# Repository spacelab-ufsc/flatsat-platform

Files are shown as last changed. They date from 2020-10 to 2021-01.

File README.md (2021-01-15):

<h1 align="center">
	SpaceLab FlatSat Platform
	<br>
</h1>

<h4 align="center">FlatSat platform designed and developed by SpaceLab.</h4>

<p align="center">
	<a href="https://github.com/spacelab-ufsc/spacelab#versioning">
		
	</a>
	<a href="https://github.com/spacelab-ufsc/flatsat-platform/releases">
		
	</a>
	<a href="https://github.com/spacelab-ufsc/flatsat-platform/releases">
		
	</a>
	<a href="https://github.com/spacelab-ufsc/flatsat-platform/commits/master">
		
	</a>
	<a href="https://github.com/spacelab-ufsc/flatsat-platform/issues">
		
	</a>
	<a href="https://github.com/spacelab-ufsc/flatsat-platform/graphs/contributors">
		
	</a>
	<a href="#license">
		
	</a>
</p>

<p align="center">
  	<a href="#overview">Overview</a> •
  	<a href="#repository-organization">Repository Organizarion</a> •
  	<a href="#license">License</a> •
  	<a href="#releases">Releases</a> •
  	<a href="#notes">Notes</a>
</p>

<p align="center">
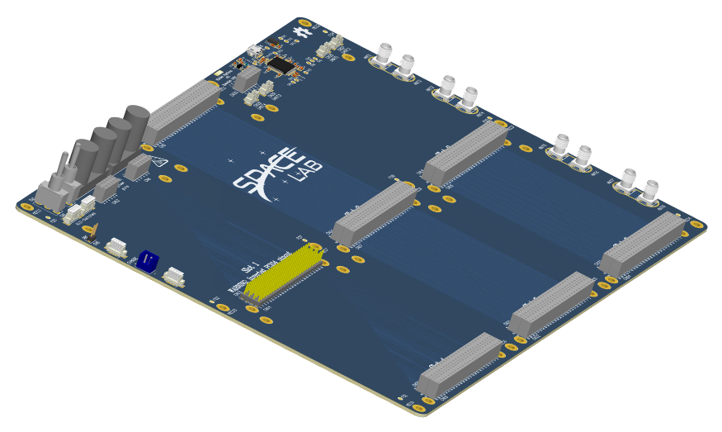
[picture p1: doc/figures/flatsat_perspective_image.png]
    
</p>

## Overview

The SpaceLab FlatSat Platform is a testbed for cubesat pcb modules. FlatSats enable easier, faster and secure method for testing subsystens indenpently or integrated in a flat design before going to assembly on a cubesat standard. The PCB can support up to 7 modules, all PC104 pins are interligated with each respective counterpart to flexibilize its use, only the particularity connection between modules need to be be taken into account.

## Repository Organization
	- doc: Technical FlatSat documentation.
	- hardware: Flatsat hardware project (sources and outputs).

## License

This project is licensed under CERN Open Hardware License (version 2) and Attribution-NoDerivatives 4.0 International (CC BY-ND 4.0).

## Releases

The FlatSat Platform hardware releases are synchronized in order to garantee compatibility. Then, using diferent versions might lead to unpredictable behavior. Refer to the [documentation](https://github.com/spacelab-ufsc/flatsat-platform/tree/master/doc) for compatibility notes.

## Notes

More info about the SpaceLab: [GitHub](https://github.com/spacelab-ufsc/spacelab) and [Website](https://spacelab.ufsc.br/en/home/).

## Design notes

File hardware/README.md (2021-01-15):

<h1 align="center">
	SpaceLab FlatSat Platform Hardware
	<br>
</h1>

<h4 align="center">FlatSat platform hardware project (sources, outputs, and documentation).</h4>

<p align="center">
    <a href="https://github.com/spacelab-ufsc/spacelab#versioning">
        
    </a>
    <a href="https://github.com/spacelab-ufsc/flatsat-platform/releases">
        
    </a>
    <a href="https://github.com/spacelab-ufsc/flatsat-platform/releases">
        
    </a>
    <a href="https://github.com/spacelab-ufsc/flatsat-platform/commits/master">
        
    </a>
    <a href="https://github.com/spacelab-ufsc/flatsat-platform/issues">
        
    </a>
    <a href="">
		
	</a>
    <a href="#license">
        
    </a>
    <a href="https://github.com/spacelab-ufsc/obdh">
        
    </a>
    <a href="https://github.com/spacelab-ufsc/flatsat-platform/tree/master/doc">
        
    </a>
</p>

<p align="center">
  	<a href="#hardware-overview">Hardware overview</a> •
  	<a href="#hardware-architecture-diagram">Architecture</a> •
  	<a href="#license">License</a> •
  	<a href="#notes">Notes</a>
</p>

<p align="center">
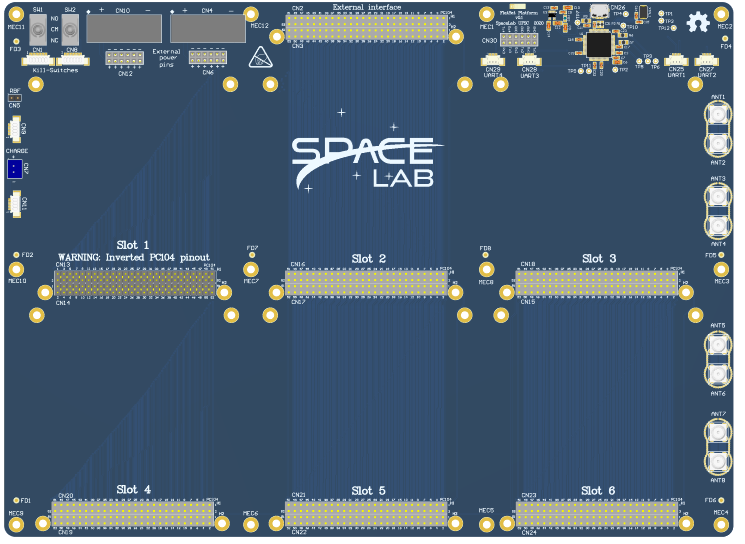
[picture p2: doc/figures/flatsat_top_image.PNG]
	
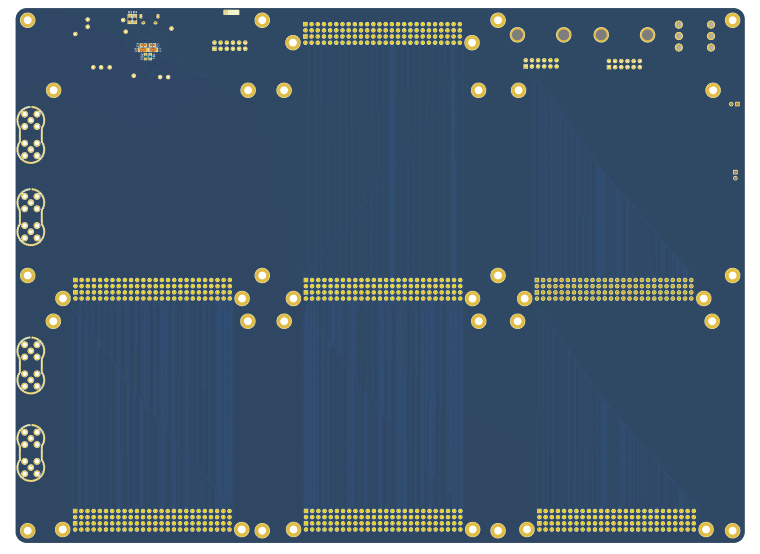
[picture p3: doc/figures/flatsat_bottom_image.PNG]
	
</p>

## Hardware overview

Currently in v0.1, the SpaceLab FlatSat Platform is a 300mmx220mm PCB composed by the following main hardware components:

* 7 PC104 connectors, one of them with inverted pinout.
* RBF pin header for a jumper and Kill-Switches with SPDTs.
* External charging for batteries thought JST and picoblade connectors.
* 2 separate binding posts (2 sets) for controled power supply and pin headers for external wiring. 
* 4 UART channels to micro USB B using FT4232H IC converter.
* 4 SMA connectors for antennas interfacing.

## Hardware architecture diagram

<p align="center">
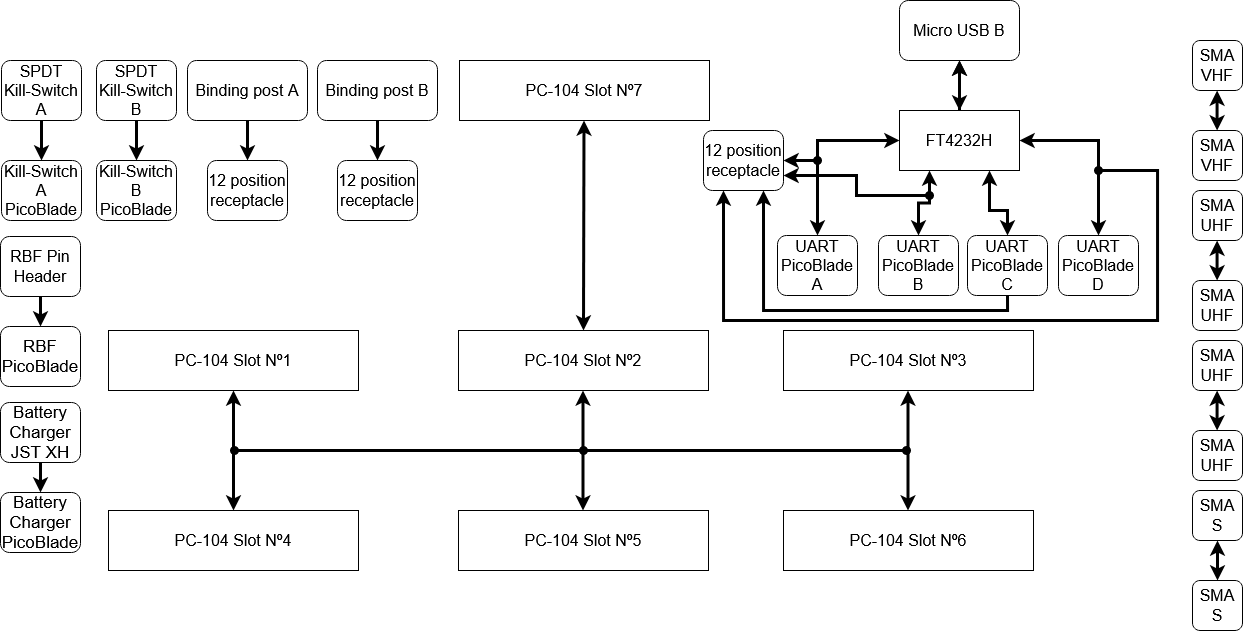
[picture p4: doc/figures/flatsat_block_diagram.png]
	
</p>

## License

The hardware part of this project is licensed under CERN Open Hardware License, version 2.

## Notes

More info about the SpaceLab: [GitHub](https://github.com/spacelab-ufsc/spacelab) and [Website](https://spacelab.ufsc.br/en/home/).

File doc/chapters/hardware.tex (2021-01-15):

%
% hardware.tex
%
% Copyright (C) 2021 by SpaceLab.
%
% Flatsat Platform Documentation
%
% This work is licensed under the Creative Commons Attribution-ShareAlike 4.0
% International License. To view a copy of this license,
% visit http://creativecommons.org/licenses/by-sa/4.0/.
%

%
% \brief Hardware chapter.
%
% \author Gabriel Mariano Marcelino <gabriel.marcelino@spacelab.ufsc.br>
% \author Yan Castro de Azeredo <yan.azeredo@spacelab.ufsc.br>
%
% \institution Universidade Federal de Santa Catarina (UFSC)
%
% \version 0.1.0
%
% \date 2020/10/11
%

\chapter{Hardware} \label{ch:hardware}

This chapter describes all the FlatSat's hardware interfaces in detail. On Figures \ref{fig:pcb-top} and \ref{fig:pcb-bottom} are displayed de top and bottom PCB prints.

\begin{figure}[!ht]
    \begin{center}
        
        \caption{FlatSat top PCB print.}
        \label{fig:pcb-top}
    \end{center}
\end{figure}

\begin{figure}[!ht]
    \begin{center}
        
        \caption{FlatSat bottom PCB print.}
        \label{fig:pcb-bottom}
    \end{center}
\end{figure}

\section{PC-104 Interfaces}

On SpaceLab's FlatSat Platform the PC-104 interfaces are composed by two 52 pins with 2.54 mm (0.1 inch) pitch connectors. Slots N$^{\circ}$2 to N$^{\circ}$7 has two \textit{SSW-126-01-G-D} and the slot N$^{\circ}$1 uses two \textit{TSW-126-07-G-D} connectors with inverted pinout, see Figures \ref{fig:n2-n7-slots} and \ref{fig:n1-slot}. All pins are interconected to flexiblesize the positioning of the modules on the platform. All slots have grounded unlabeled mounting holes for the modules, the labeled MEC1 to MEC12 holes are for the FlatStats stability feet.

\begin{figure}[!ht]
    \begin{center}
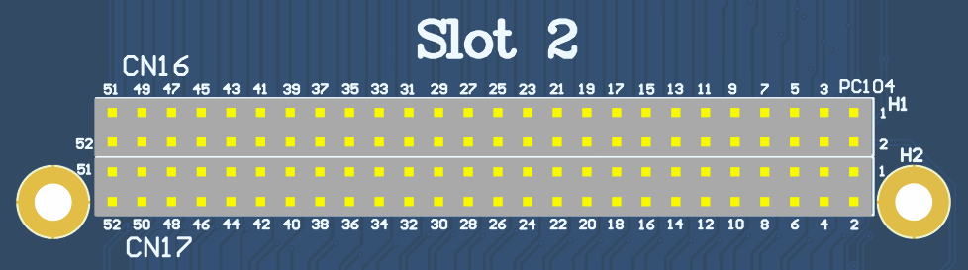
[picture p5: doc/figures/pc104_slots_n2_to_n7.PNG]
        
        \caption{FlatSat N$^{\circ}$2 PC-104 slot.}
        \label{fig:n2-n7-slots}
    \end{center}
\end{figure}

\begin{figure}[!ht]
    \begin{center}
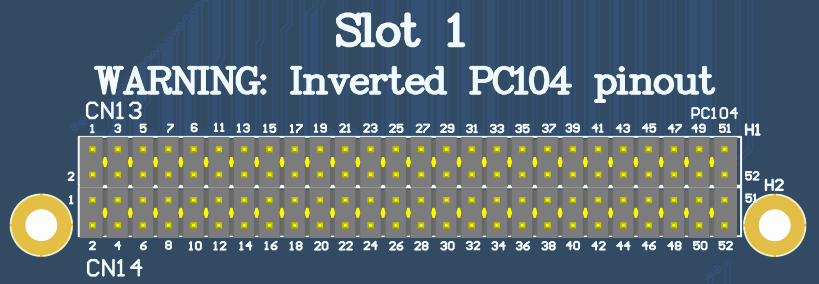
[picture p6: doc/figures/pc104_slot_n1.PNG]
        
        \caption{FlatSat N$^{\circ}$1 PC-104 slot.}
        \label{fig:n1-slot}
    \end{center}
\end{figure}

\section{Binding Posts and Power Receptacles}

Two sets of binding posts (\textit{4243-0}) can be mouted on the labeled CN4 and CN10 hole pads to be used for two external power supplies, see \autoref{fig:binding-posts}. The modules are powered via external jumper wires to the 12 position receptacle connectors (\textit{BCS-106-L-D-TE}) labeled CN6 and CN12. On the silkscreen the plus (+) signs are the positive power pins while the minus (-) signs are the GND pins.

\begin{figure}[!ht]
    \begin{center}
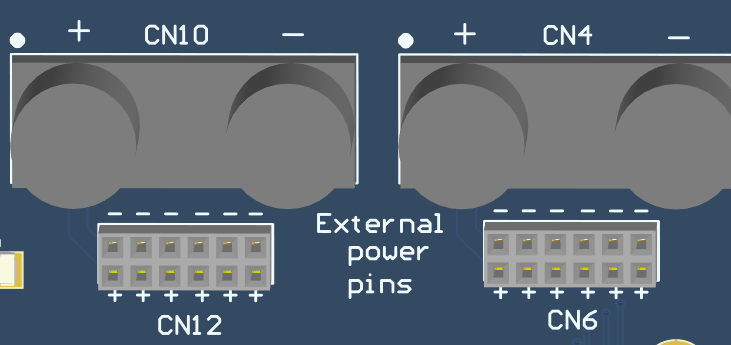
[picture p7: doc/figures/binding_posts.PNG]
        
        \caption{FlatSat binding posts and power receptables.}
        \label{fig:binding-posts}
    \end{center}
\end{figure}

\section{Charge Header}

On the board there is a JST XH 2 position header (\textit{B2B-XH-A-M(LF)(SN)}) for charging batteries, it can be seen in \autoref{fig:charge-connectors}. The component can suport up to 3000 mA of current, but it is advised to be used with less than 1500 mA. The 4 pin PicoBlade is to be connected to the EPS\nomenclature{\textbf{EPS}}{\textit{Electric Power System.}} module to make the interconnection for the JST header. The charge header also provides a detent lock for fastening and avoid a mistankenly reverse connection.

\begin{figure}[!ht]
    \begin{center}
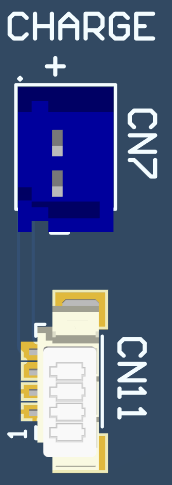
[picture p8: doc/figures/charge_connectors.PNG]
        
        \caption{FlatSat charge connectors.}
        \label{fig:charge-connectors}
    \end{center}
\end{figure}

\section{RBF Pin Header}

The platform has a RBF pin header that can seen \autoref{fig:rbf-connectors}. The interconnection between the header and the EPS module is done by a 4 pin PicoBlade.

\begin{figure}[!ht]
    \begin{center}
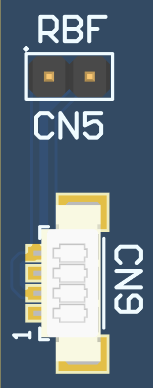
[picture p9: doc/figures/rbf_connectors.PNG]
        
        \caption{FlatSat RBF connectors.}
        \label{fig:rbf-connectors}
    \end{center}
\end{figure}

\section {SPDT Kill-Switches}

The kill-switches uses SPDT switches (\textit{100SP1T1B4M2QE}) for powering off the EPS module, see \autoref{fig:kill-switches-connectors}. The power off states are seen on \autoref{fig:kill-switches-states}, they are also present on the hardware schematics. The SPDTs are interconnected to the EPS module via two 6 pin PicoBlade connectors labeled CN1 and CN8.

\begin{figure}[!ht]
    \begin{center}
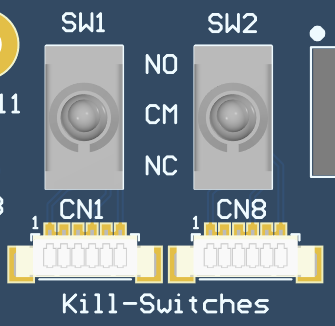
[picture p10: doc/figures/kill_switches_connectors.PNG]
        
        \caption{FlatSat kill-switches connectors.}
        \label{fig:kill-switches-connectors}
    \end{center}
\end{figure}

\begin{figure}[!ht]
    \begin{center}
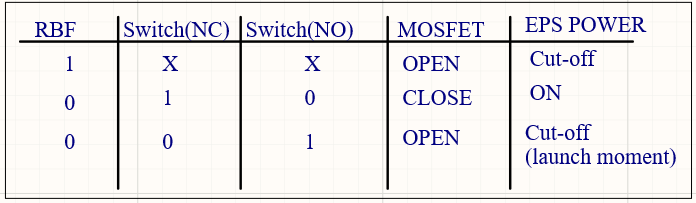
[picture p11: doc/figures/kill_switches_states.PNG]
        
        \caption{FlatSat kill-switches states.}
        \label{fig:kill-switches-states}
    \end{center}
\end{figure}

\section{Antenna Interfaces}

\subsection{SMA connectors}

On the PCB there are SMA connectors (\textit{132134-15}) labeled ANT1 to ANT8 for connecting VHF\nomenclature{\textbf{VHF}}{\textit{Very High Frequency.}}, UHF\nomenclature{\textbf{UHF}}{\textit{Ultra High Frequency.}} and S-Band antennas, see \autoref{fig:antennas-smas}. The receiver (RX) antenna is to be connected to one of the SMA, while the transmitter (TX) goes to the other connector and to the CubeSat module. The impedance control (see \autoref{fig:rf-track-width-calc}) and power dissipation (see \autoref{fig:rf-track-width-power-calc}) where approximately calculated for all 3 bands. As the FlatSat platform is to be used in light testing the aproximations where considered acceptable for the project.

\begin{figure}[!ht]
    \begin{center}
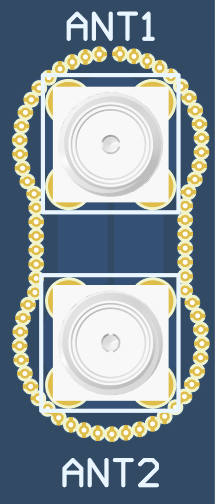
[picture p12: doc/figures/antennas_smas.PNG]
        
        \caption{FlatSat SMA connectors.}
        \label{fig:antennas-smas}
    \end{center}
\end{figure}

\subsection{Impedance Control of the RF Tracks}

\begin{figure}[!ht]
    \begin{center}
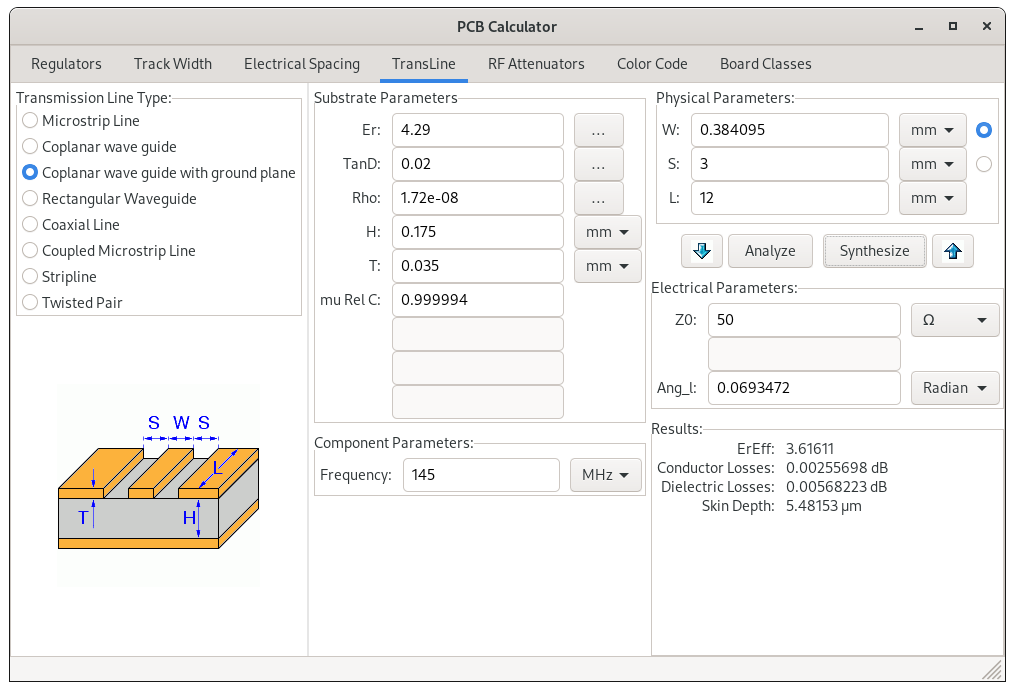
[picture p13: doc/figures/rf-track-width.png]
        
        \caption{Calculation of the width of the RF tracks.}
        \label{fig:rf-track-width-calc}
    \end{center}
\end{figure}

\begin{figure}[!ht]
    \begin{center}
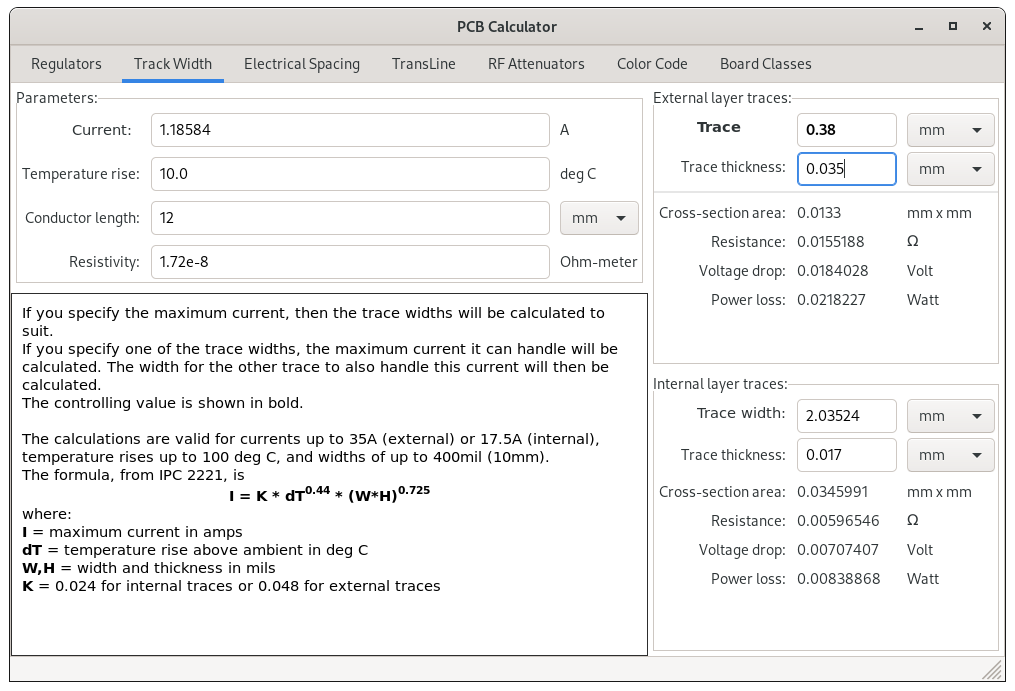
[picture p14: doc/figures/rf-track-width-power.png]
        
        \caption{Power dissipation of the RF tracks.}
        \label{fig:rf-track-width-power-calc}
    \end{center}
\end{figure}

\section{UART to USB Converter}

There is a UART to USB converter circuit built-in the FlatSat platform for debbuging pourposes for four independent modules, it can be seen on \autoref{fig:ft4232h-circuit}. The subcircuit is self powered from a USB cable connecting a computer to a micro USB type B port (\textit{10118194-0001LF}). The USB Bridge converter IC\nomenclature{\textbf{IC}}{\textit{Integrated Circuit.}} is the \textit{FT4232HL-REEL} from FTDI. PicoBlade connectors are used for connecting the IC to the modules, see Figures \ref{fig:uart-picoblades-1} and \ref{fig:uart-picoblades-2}. It is also possible to use jumper wires connecting the 12 Position receptacle connector (\textit{BCS-106-L-D-TE}) labeled CN30 to the modules if PicoBlades are not used.

\begin{figure}[!ht]
    \begin{center}
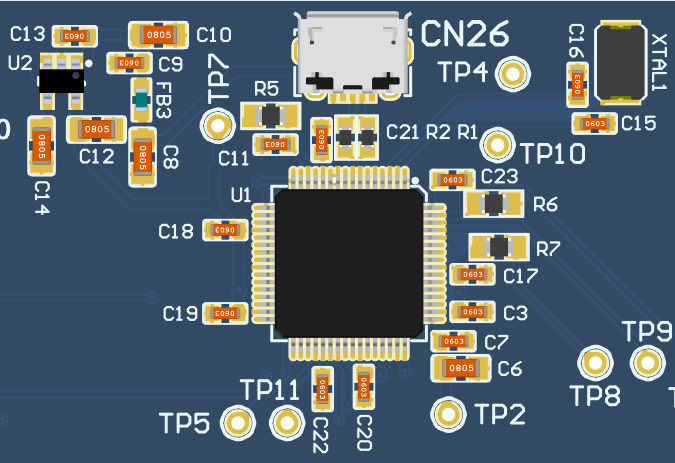
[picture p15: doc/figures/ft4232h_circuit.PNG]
        
        \caption{Top view of the UART to USB converter circuit.}
        \label{fig:ft4232h-circuit}
    \end{center}
\end{figure}

\begin{figure}[!ht]
    \begin{center}
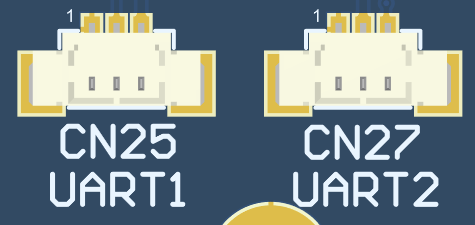
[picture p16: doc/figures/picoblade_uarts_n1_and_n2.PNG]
        
        \caption{UART PicoBlade N$^{\circ}$1 and N$^{\circ}$2 connectors.}
        \label{fig:uart-picoblades-1}
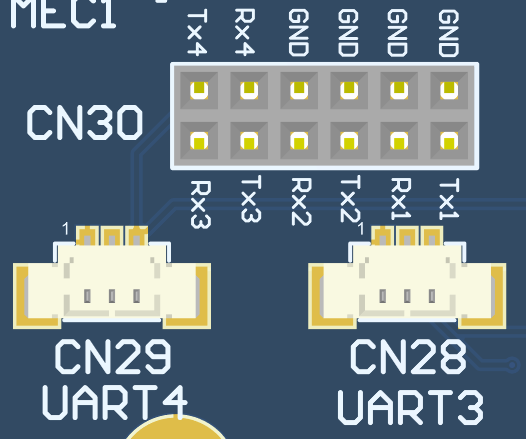
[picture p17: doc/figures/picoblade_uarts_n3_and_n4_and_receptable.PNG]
        
        \caption{UART PicoBlade N$^{\circ}$3 and N$^{\circ}$4 connectors and receptable.}
        \label{fig:uart-picoblades-2}
    \end{center}
\end{figure}

\section{Test Points}

The FlatSat has test points for the UART to USB converter circuit. The \autoref{tab:testpoints} displays their labels and description.

\begin{table}[!h]
    \centering
    \begin{tabular}{cllll}
        \toprule[1.5pt]
        \textit{Label} & \textit{Description} \\
        \midrule
        TP1                & (VPLL) 3V3 FT4232H power input. \\
        TP2                & (VREGOUT) 1V8 FT4232H internal power output. \\
        TP3                & (VPHY) 3V3 FT4232H power input. \\
        TP4                & (REF) Current reference for FT4232H. \\
        TP5                & (RESET\#) Reset input for FT4232H. \\
        TP6                & (EECS) EEPROM chip select - pulled down by 10k resistor. \\
        TP7                & (VCCIO) I/O interface 3V3 power supply input. \\
        TP8                & (EEDATA) EEPROM data I/O - pulled up by 10k resistor. \\
        TP9                & (EECLK) Clock signal to EEPROM - not used. \\
        TP10               & (PWREN\#) Active low power-enable output. \\
        TP11               & (SUSPEND\#) Active low when USB is in suspend mode. \\
        TP12               & (GND) 0V ground input for FT4232H.\\
        \bottomrule[1.5pt]
    \end{tabular}
    \caption{FlatSat test points.}
    \label{tab:testpoints}
\end{table}

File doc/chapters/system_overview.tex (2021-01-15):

%
% system_overview.tex
%
% Copyright (C) 2021 by SpaceLab.
%
% Flatsat Platform Documentation
%
% This work is licensed under the Creative Commons Attribution-ShareAlike 4.0
% International License. To view a copy of this license,
% visit http://creativecommons.org/licenses/by-sa/4.0/.
%

%
% \brief System Overview chapter.
%
% \author Gabriel Mariano Marcelino <gabriel.marcelino@spacelab.ufsc.br>
% \author Yan Castro de Azeredo <yan.azeredo@spacelab.ufsc.br>
%
% \institution Universidade Federal de Santa Catarina (UFSC)
%
% \version 0.1.0
%
% \date 2020/12/17
%

\chapter{System Overview} \label{ch:system-overview}

The FlatSat form factor choosen for this project is a retangular one piece design. On its current version v0.1 the platform can be purelly used hardware wise. The hardware block diagram can be seen on \autoref{fig:block-diagram}. The PC-104 slot N$^{\circ}$7 is supossed to be used for a extra interface, shield or another FlatSat platform.

\section{Block Diagram}

\begin{figure}[!ht]
    \begin{center}
        
        \caption{FlatSat hardware block diagram.}
        \label{fig:block-diagram}
    \end{center}
\end{figure}

\section{Board Dimensions}

The board is a retangular PCB with linear dimensions of 300$\times$220 mm. The full mechanical specs of the platform can be seen on its draftsman document available at it's GitHub repository \cite{flatsat-draftsman}.

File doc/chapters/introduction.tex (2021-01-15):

%
% introduction.tex
%
% Copyright (C) 2020 by SpaceLab.
%
% Flatsat Platform Documentation
%
% This work is licensed under the Creative Commons Attribution-ShareAlike 4.0
% International License. To view a copy of this license,
% visit http://creativecommons.org/licenses/by-sa/4.0/.
%

%
% \brief Introduction chapter.
%
% \authors: Gabriel Mariano Marcelino <gabriel.marcelino@spacelab.ufsc.br> and Yan Castro de Azeredo <yan.azeredo@spacelab.ufsc.br>
%
% \institution Universidade Federal de Santa Catarina (UFSC)
%
% \version 0.1.0
%
% \date 2020/07/16
%

\chapter{Introduction} \label{ch:introduction}

The SpaceLab FlatSat Platform is a testbed for CubeSat PCB\nomenclature{\textbf{PCB}}{\textit{Printed Circuit Board.}} modules. FlatSats enable easier, faster and a secure method for testing subsystens independently while been integrated in a flat design before going to integration on a CubeSat form factor. The PCB can support up to 7 modules, all PC-104 pins are interligated to flexibilize its use, only the particularity connection between modules need to be be taken into account. One PC-104 has inverted pinout, the board also makes it possible to have two seperate power supplies, a UART\nomenclature{\textbf{UART}}{\textit{Universal Asynchronous Receiver/Transmitter.}} to USB\nomenclature{\textbf{USB}}{\textit{Universal Serial Bus.}} converter for 4 modules, kill-switches activation though SPDTs\nomenclature{\textbf{SPDT}}{\textit{Single Pole, Double Throw.}}, Remove Before Flight (RBF\nomenclature{\textbf{RBF}}{\textit{Remove Before Flight.}}) pin header, connector for charging batteries and SMA\nomenclature{\textbf{SMA}}{\textit{SubMiniature version A.}} connectors for antennas. This project is to be used on the GOLDS-UFSC mission \cite{golds-ufsc} during test phase.

\begin{figure}[!ht]
    \begin{center}
        
        \caption{3D view of the FlatSat PCB.}
        \label{fig:pcb-3d}
    \end{center}
\end{figure}

All the project, source and documentation files are available freely on a GitHub repository \cite{flatsat-platform-repo} under its respective licenses.

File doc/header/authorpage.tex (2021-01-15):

%
% authorpage.tex
%
% Copyright (C) 2021 SpaceLab.
%
% Flatsat Platform Documentation
%
% This work is licensed under the Creative Commons Attribution-ShareAlike 4.0
% International License. To view a copy of this license,
% visit http://creativecommons.org/licenses/by-sa/4.0/.
%

%
% \brief Author page.
%
% \author Gabriel Mariano Marcelino <gabriel.marcelino@spacelab.ufsc.br>
%
% \institution Universidade Federal de Santa Catarina (UFSC)
%
% \version 0.1.0
%
% \date 2020/07/16
%

\thispagestyle{empty}

\begin{center}

\textbf{\thetitle}

\textit{January, 2021}

\vspace{1cm}

\textbf{Project Chief:}

Eduardo Augusto Bezerra

\vspace{1cm}

\textbf{Authors:}

Yan Castro de Azeredo \\

\vspace{1cm}

\textbf{Contributing Authors:}

Gabriel Mariano Marcelino \\
André Martins Pio de Mattos \\

\vspace{1cm}

\textbf{Revision Control:}

\end{center}

\begin{table}[!ht]
    \begin{center}
        \begin{tabular}{cL{5cm}L{5.5cm}C{2cm}}
            \toprule[1.5pt]
            \textbf{Version} & \textbf{Author}  & \textbf{Changes}    & \textbf{Date} \\
            \midrule
            0.0     & G. M. Marcelino           & Document creation   & 2020/10/11 \\
            0.1     & Y. C. de Azeredo          & First release       & 2021/01/04 \\
                    &                           &                     &            \\
                    &                           &                     &            \\
            \bottomrule[1.5pt]
        \end{tabular}
    \end{center}
\end{table}

\vfill

\begin{figure}[!h]
	\begin{center}
		
	\end{center}
\end{figure}

\textcopyright\  2021 by SpaceLab. \thetitle. This work is licensed under the Creative Commons Attribution-ShareAlike 4.0 International License. To view a copy of this license, visit \href{http://creativecommons.org/licenses/by-sa/4.0/}{http://creativecommons.org/licenses/by-sa/4.0/}.

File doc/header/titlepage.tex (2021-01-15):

%
% titlepage.tex
%
% Copyright (C) 2021 by SpaceLab.
%
% Flatsat Platform Documentation
%
% This work is licensed under the Creative Commons Attribution-ShareAlike 4.0
% International License. To view a copy of this license,
% visit http://creativecommons.org/licenses/by-sa/4.0/.
%

%
% \brief Title page.
%
% \author Gabriel Mariano Marcelino <gabriel.marcelino@spacelab.ufsc.br>
%
% \institution Universidade Federal de Santa Catarina (UFSC)
%
% \version 0.1.0
%
% \date 2020/07/16
%

\begin{titlepage}

\thispagestyle{empty}

\begin{flushleft}
SLB-FLATSAT-DOC-v0.1
\end{flushleft}

\vspace{1cm}

\begin{figure}[!ht]
    \begin{flushleft}
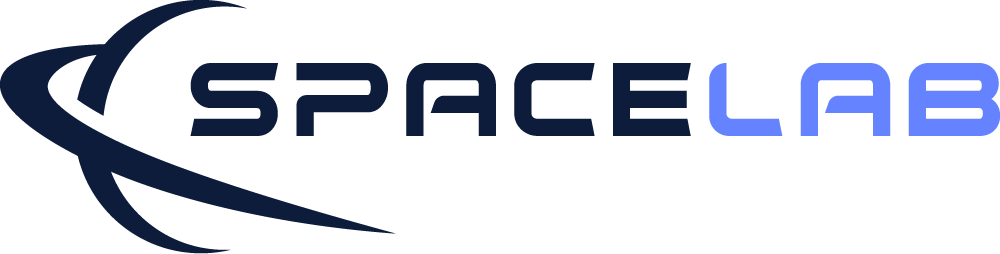
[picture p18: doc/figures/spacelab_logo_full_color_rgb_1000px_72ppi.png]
        
    \end{flushleft}
\end{figure}

\begin{flushleft}
\Huge{\textbf{\thetitle}}
\rule[0pt]{\textwidth}{5pt}
\end{flushleft}

\vspace{0.2cm}

\begin{flushleft}
\textit{\thetitle} \\
\textit{SpaceLab, Universidade Federal de Santa Catarina, Florianópolis - Brazil}
\end{flushleft}

\vfill
\vfill

\begin{flushright}
January 2021
\end{flushright}

\end{titlepage}

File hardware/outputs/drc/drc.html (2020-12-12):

Altium

# Design Rule Verification Report

Date: | | 11/5/2020
Time: | | 8:09:18 PM
Elapsed Time: | | 00:00:04
Filename: | | C:\Users\Yan Azeredo\Desktop\SpaceLab\flatsat-platform\hardware\sources\board_layout.PcbDoc

Warnings: | | 0
Rule Violations: | | 0

## Summary

Warnings | Count
Total | 0

Rule Violations | Count
Clearance Constraint (Gap=0.178mm) (InNetClass('S')),(InNetClass('S')) | 0
Clearance Constraint (Gap=0.178mm) (All),(All) | 0
Short-Circuit Constraint (Allowed=No) (All),(All) | 0
Un-Routed Net Constraint ( (All) ) | 0
Modified Polygon (Allow modified: No), (Allow shelved: No) | 0
Width Constraint (Min=0.127mm) (Max=1.778mm) (Preferred=0.381mm) (All) | 0
Power Plane Connect Rule(Direct Connect )(Expansion=0.508mm) (Conductor Width=0.254mm) (Air Gap=0.254mm) (Entries=4) (Not All) | 0
Power Plane Connect Rule(Relief Connect )(Expansion=0.508mm) (Conductor Width=0.254mm) (Air Gap=0.254mm) (Entries=4) (All) | 0
Power Plane Connect Rule(Direct Connect )(Expansion=0.508mm) (Conductor Width=0.254mm) (Air Gap=0.254mm) (Entries=4) (InNetClass('power')) | 0
Hole Size Constraint (Min=0.025mm) (Max=5.08mm) (All) | 0
Hole To Hole Clearance (Gap=0.254mm) (All),(All) | 0
Minimum Solder Mask Sliver (Gap=0mm) (All),(All) | 0
Silk To Solder Mask (Clearance=0mm) (IsPad),(All) | 0
Silk to Silk (Clearance=0.127mm) (All),(All) | 0
Net Antennae (Tolerance=0mm) (All) | 0
Height Constraint (Min=0mm) (Max=1790.783mm) (Prefered=12.7mm) ('PCB_Project_Batteries') | 0
Total | 0

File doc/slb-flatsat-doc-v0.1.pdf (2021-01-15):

SLB-FLATSAT-DOC-v0.1

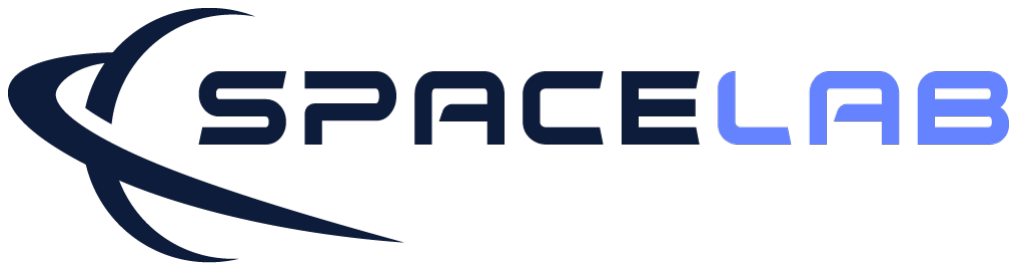
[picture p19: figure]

# Flatsat Platform Documentation

Flatsat Platform Documentation
SpaceLab, Universidade Federal de Santa Catarina, Florianópolis - Brazil

January 2021

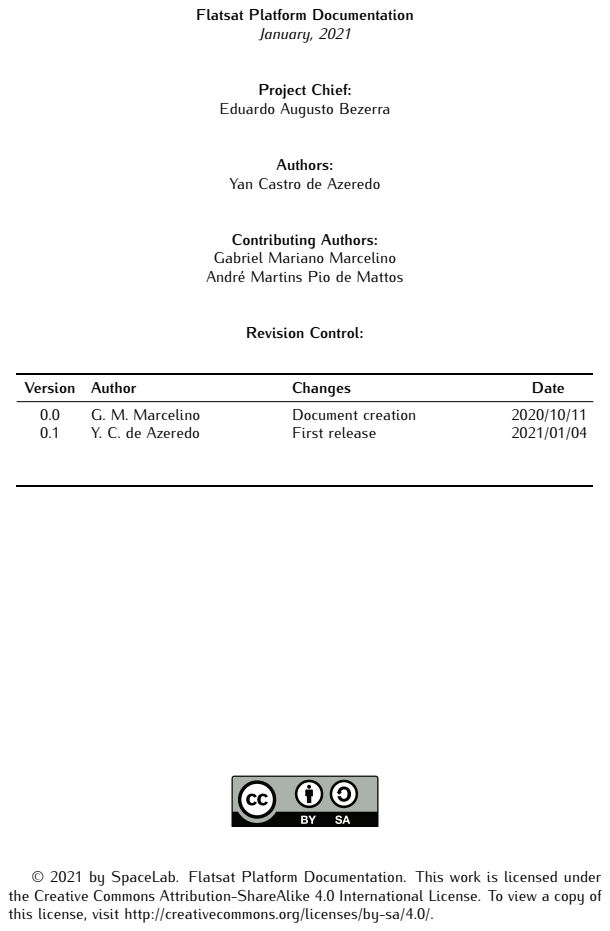
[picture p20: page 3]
January, 2021; Authors:; Revision Control:; Version Author; Changes; Date; G. M. Marcelino; Document creation; Y. C. de Azeredo; First release

Flatsat Platform Documentation

Project Chief:
Eduardo Augusto Bezerra

Yan Castro de Azeredo

Contributing Authors:
Gabriel Mariano Marcelino
André Martins Pio de Mattos

© 2021 by SpaceLab. Flatsat Platform Documentation. This work is licensed under
the Creative Commons Attribution-ShareAlike 4.0 International License. To view a copy of
this license, visit http://creativecommons.org/licenses/by-sa/4.0/.

## List of Figures

1.1 3D view of the FlatSat PCB | | 1
2.1 FlatSat hardware block diagram | | 3
3.1 FlatSat top PCB print | | 5
3.2 FlatSat bottom PCB print | | 6
3.3 FlatSat N◦2 PC-104 slot | | 6
3.4 FlatSat N◦1 PC-104 slot | | 6
3.5 FlatSat binding posts and power receptables | | 7
3.6 FlatSat charge connectors | | 7
3.7 FlatSat RBF connectors | | 8
3.8 FlatSat kill-switches connectors | | 8
3.9 FlatSat kill-switches states | | 9
3.10 FlatSat SMA connectors | | 9
3.11 Calculation of the width of the RF tracks | | 10
3.12 Power dissipation of the RF tracks | | 11
3.13 Top view of the UART to USB converter circuit | | 11
3.14 UART PicoBlade N◦1 and N◦2 connectors | | 12
3.15 UART PicoBlade N◦3 and N◦4 connectors and receptable | | 12
4.1 Bottom view of the UART to USB converter circuit | | 14
4.2 EPS mounted on N◦1 slot on a EDA tool | | 14
4.3 OBDH mounted on N◦2 slot on a EDA tool | | 14

v

## List of Tables

3.1 FlatSat test points | 12

vii

## Nomenclature

AWG | American Wire Gauge.
BOM | Bill Of Materials.
DC | Direct Current.
DNP | Do Not Place.

EEPROM Electrically-Erasable Programmable Read-Only Memory.

EMC | Electromagnetic Compatibility.
EPS | Electric Power System.
IC | Integrated Circuit.
OBDH | On-Board Data Handling.
PCB | Printed Circuit Board.
PC | Personal Computer.
RBF | Remove Before Flight.
SMA | SubMiniature version A.
SPDT | Single Pole, Double Throw.
UART | Universal Asynchronous Receiver/Transmitter.
UHF | Ultra High Frequency.
USB | Universal Serial Bus.
VHF | Very High Frequency.

ix

## Contents

List of Figures | v
List of Tables | vii
Nomenclature | ix
1 Introduction | 1
2 System Overview | 3
3 Hardware | 5
4 Board Assembly | 13
5 Usage Instructions | 15
References | 17

xi

## CHAPTER 1

## Introduction

The SpaceLab FlatSat Platform is a testbed for CubeSat PCB modules. FlatSats enable easier, faster and a secure method for testing subsystens independently while been integrated in a flat design before going to integration on a CubeSat form factor. The PCB can support up to 7 modules, all PC-104 pins are interligated to flexibilize its use, only the particularity connection between modules need to be be taken into account. One PC-104 has inverted pinout, the board also makes it possible to have two seperate power supplies, a UART to USB converter for 4 modules, kill-switches activation though SPDTs, Remove Before Flight (RBF) pin header, connector for charging batteries and SMA connectors for antennas. This project is to be used on the GOLDS-UFSC mission
[1] during test phase.

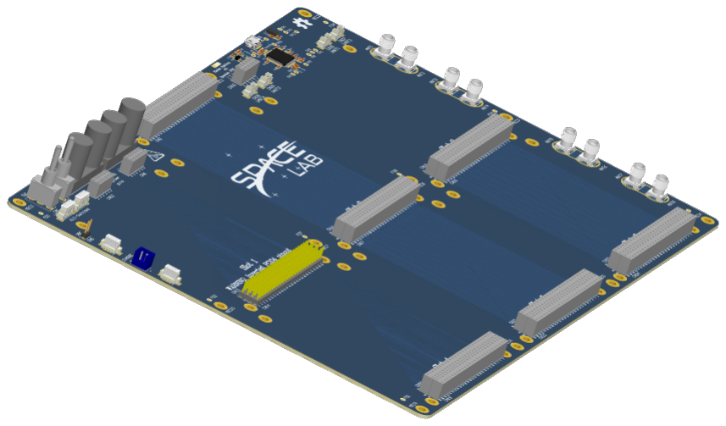
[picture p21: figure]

Figure 1.1: 3D view of the FlatSat PCB.

All the project, source and documentation files are available freely on a GitHub repository [2] under its respective licenses.

## CHAPTER 2

## System Overview

The FlatSat form factor choosen for this project is a retangular one piece design. On its current version v0.1 the platform can be purelly used hardware wise. The hardware block diagram can be seen on Figure 2.1. The PC-104 slot N◦7 is supossed to be used for a extra interface, shield or another FlatSat platform.

## 2.1 Block Diagram

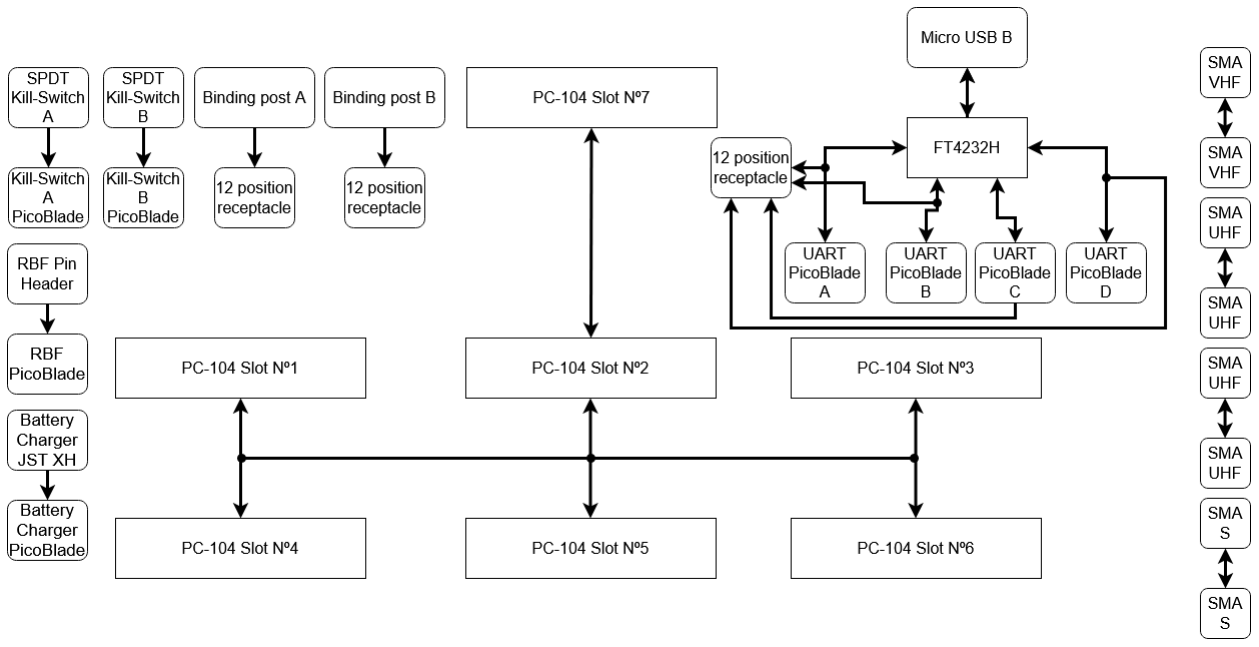
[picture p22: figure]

Figure 2.1: FlatSat hardware block diagram.

## 2.2 Board Dimensions

The board is a retangular PCB with linear dimensions of 300×220 mm. The full mechanical specs of the platform can be seen on its draftsman document available at it’s GitHub repository [3].

## CHAPTER 3

## Hardware

This chapter describes all the FlatSat’s hardware interfaces in detail. On Figures 3.1 and 3.2 are displayed de top and bottom PCB prints.

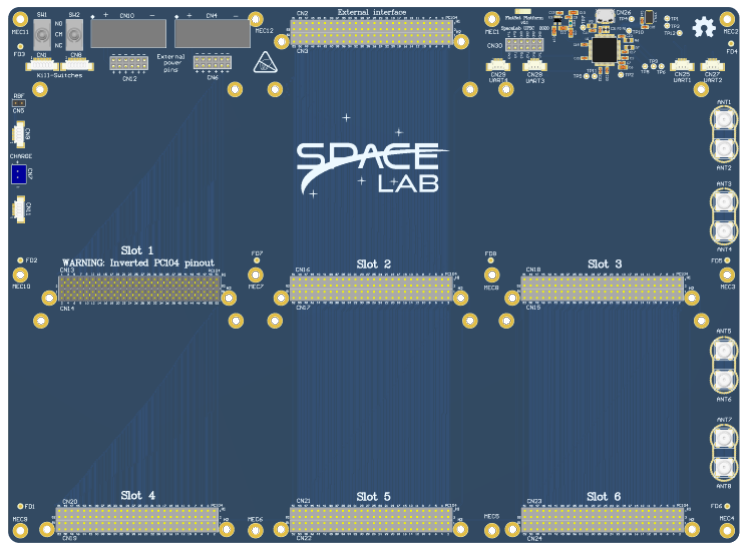
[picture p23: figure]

Figure 3.1: FlatSat top PCB print.

## 3.1 PC-104 Interfaces

On SpaceLab’s FlatSat Platform the PC-104 interfaces are composed by two 52 pins with 2.54 mm (0.1 inch) pitch connectors. Slots N◦2 to N◦7 has two SSW-126-01-G-D and the slot N◦1 uses two TSW-126-07-G-D connectors with inverted pinout, see Figures 3.3 and 3.4. All pins are interconected to flexiblesize the positioning of the modules on the platform. All slots have grounded unlabeled mounting holes for the modules, the labeled MEC1 to MEC12 holes are for the FlatStats stability feet.

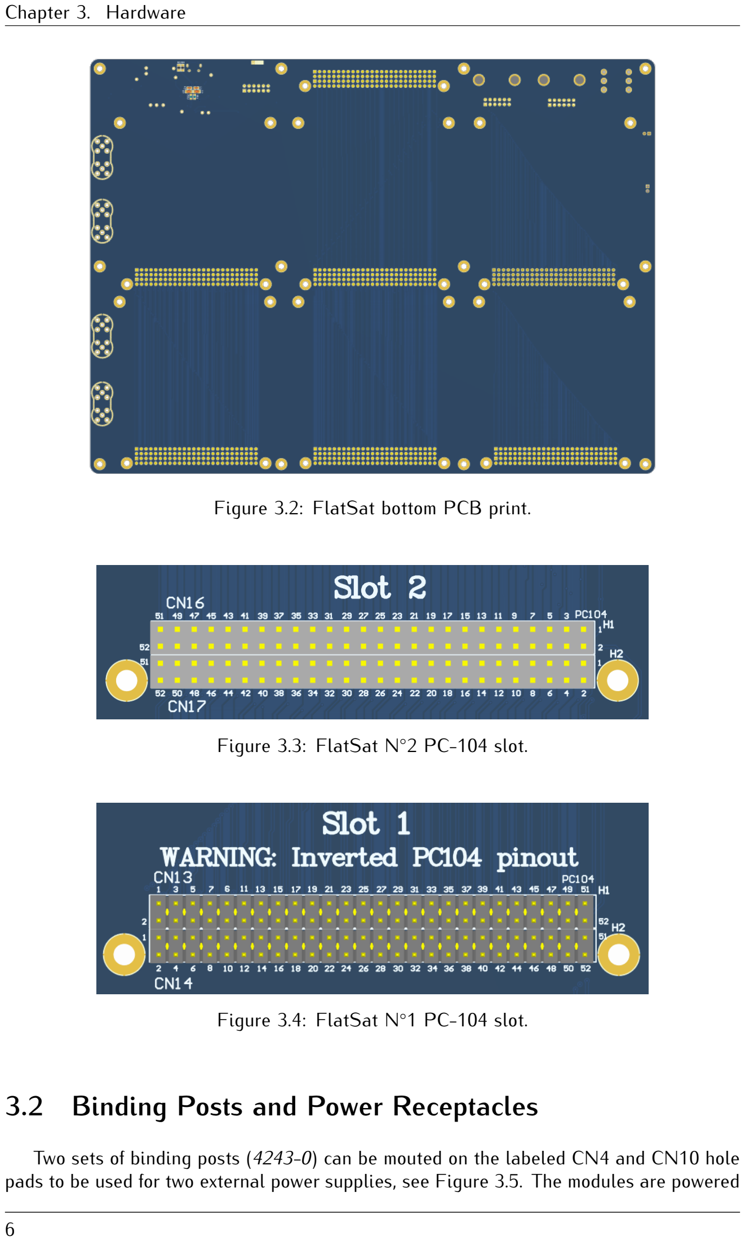
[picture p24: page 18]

Chapter 3. Hardware

Figure 3.2: FlatSat bottom PCB print.

Figure 3.3: FlatSat N◦2 PC-104 slot.

Figure 3.4: FlatSat N◦1 PC-104 slot.

## 3.2 Binding Posts and Power Receptacles

Two sets of binding posts (4243-0) can be mouted on the labeled CN4 and CN10 hole pads to be used for two external power supplies, see Figure 3.5. The modules are powered

3.3. Charge Header

via external jumper wires to the 12 position receptacle connectors (BCS-106-L-D-TE) labeled CN6 and CN12. On the silkscreen the plus (+) signs are the positive power pins while the minus (-) signs are the GND pins.


Figure 3.5: FlatSat binding posts and power receptables.

## 3.3 Charge Header

On the board there is a JST XH 2 position header (B2B-XH-A-M(LF)(SN)) for charging batteries, it can be seen in Figure 3.6. The component can suport up to 3000 mA of current, but it is advised to be used with less than 1500 mA. The 4 pin PicoBlade is to be connected to the EPS module to make the interconnection for the JST header. The charge header also provides a detent lock for fastening and avoid a mistankenly reverse connection.

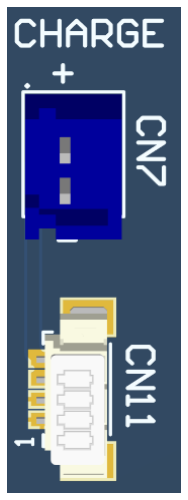
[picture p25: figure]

Figure 3.6: FlatSat charge connectors.

Chapter 3. Hardware

## 3.4 RBF Pin Header

The platform has a RBF pin header that can seen Figure 3.7. The interconnection between the header and the EPS module is done by a 4 pin PicoBlade.


Figure 3.7: FlatSat RBF connectors.

## 3.5 SPDT Kill-Switches

The kill-switches uses SPDT switches (100SP1T1B4M2QE) for powering off the EPS module, see Figure 3.8. The power off states are seen on Figure 3.9, they are also present on the hardware schematics. The SPDTs are interconnected to the EPS module via two 6 pin PicoBlade connectors labeled CN1 and CN8.


Figure 3.8: FlatSat kill-switches connectors.

3.6. Antenna Interfaces


Figure 3.9: FlatSat kill-switches states.

## 3.6 Antenna Interfaces

### 3.6.1 SMA connectors

On the PCB there are SMA connectors (132134-15) labeled ANT1 to ANT8 for connecting VHF, UHF and S-Band antennas, see Figure 3.10. The receiver (RX) antenna is to be connected to one of the SMA, while the transmitter (TX) goes to the other connector and to the CubeSat module. The impedance control (see Figure 3.11) and power dissipation (see Figure 3.12) where approximately calculated for all 3 bands. As the FlatSat platform is to be used in light testing the aproximations where considered acceptable for the project.


Figure 3.10: FlatSat SMA connectors.

### 3.6.2 Impedance Control of the RF Tracks

## 3.7 UART to USB Converter

There is a UART to USB converter circuit built-in the FlatSat platform for debbuging pourposes for four independent modules, it can be seen on Figure 3.13. The subcircuit is self powered from a USB cable connecting a computer to a micro USB type B port (10118194-0001LF). The USB Bridge converter IC is the FT4232HL-REEL from FTDI. PicoBlade connectors are used for connecting the IC to the modules, see Figures 3.14

Chapter 3. Hardware


Figure 3.11: Calculation of the width of the RF tracks.

and 3.15. It is also possible to use jumper wires connecting the 12 Position receptacle connector (BCS-106-L-D-TE) labeled CN30 to the modules if PicoBlades are not used.

## 3.8 Test Points

The FlatSat has test points for the UART to USB converter circuit. The Table 3.1 displays their labels and description.


3.8. Test Points

Figure 3.12: Power dissipation of the RF tracks.

Figure 3.13: Top view of the UART to USB converter circuit.

Chapter 3. Hardware


Figure 3.14: UART PicoBlade N◦1 and N◦2 connectors.


Figure 3.15: UART PicoBlade N◦3 and N◦4 connectors and receptable.

Label Description

TP1 | (VPLL) 3V3 FT4232H power input.
TP2 | (VREGOUT) 1V8 FT4232H internal power output.
TP3 | (VPHY) 3V3 FT4232H power input.
TP4 | (REF) Current reference for FT4232H.
TP5 | (RESET#) Reset input for FT4232H.
TP6 | (EECS) EEPROM chip select - pulled down by 10k resistor.
TP7 | (VCCIO) I/O interface 3V3 power supply input.
TP8 | (EEDATA) EEPROM data I/O - pulled up by 10k resistor.
TP9 | (EECLK) Clock signal to EEPROM - not used.
TP10 (PWREN#) Active low power-enable output.
TP11 (SUSPEND#) Active low when USB is in suspend mode. TP12 (GND) 0V ground input for FT4232H.

Table 3.1: FlatSat test points.

## CHAPTER 4

## Board Assembly

The hardware project has the Bill of Material (BOM) avalaible at its GitHub repository in excel spreeadsheets format. The PCB can be assembled by a Pick-and-place machine using the .txt file found on the hardware/fabrication folder if desired, fiducials labeled FD# are placed to make this possible.

## 4.1 FlatSat Stabillity Feet

On the PCB there are labeled MEC1 to MEC12 mouting holes on the edges and in the middle of the board to be used for stabillity feet when the board is placed on top of a test bench.

## 4.2 DNP Components

There is only one Do Not Place (DNP) component present in the USB to UART circuit, it is the labeled R4 pad with 0805 size (2012 metric) available for soldering the micro USB type B chassi to GND for Electromagnetic compatibility (EMC) see Figure 4.1. This can be done soldering a zero-Ohm resistor for a DC path or capacitor for a high-frequency path between shield and signal ground, see Section 2.2.2 of the document [4] for more details.

## 4.3 Modules Mounting

The PC-104 slots N◦2 to N◦7 are compatible for CubeSat PCB modules that are stacked in middle or the first on top. The slot N◦1 can only be used for the last module on this stack because of the inverted pinout. For the case of the SpaceLab’s CubeSat stackup of the core modules, the last module of the stack is the EPS. For this case the EPS needs to be mounted up-side-down on slot N◦1 as can be seen on Figure 4.2. For other modules any other PC-104 slots can be used, the OBDH is showed mouted on Figure 4.3.

## 4.4 Antennas Connection

Since the SMA connectors present on the board are on the right far side, modules placed in the opposite side may not be in reach for the connection. Because of this reason is recommended to use slots N◦1 and N◦4 for non antenna dependents PCBs.


Chapter 4. Board Assembly

Figure 4.1: Bottom view of the UART to USB converter circuit.

Figure 4.2: EPS mounted on N◦1 slot on a EDA tool.

Figure 4.3: OBDH mounted on N◦2 slot on a EDA tool.

## CHAPTER 5

## Usage Instructions

## 5.1 Charging Batteries Through Connector

To charge the batteries it will be needed a cable compatible with the JST XH header. The compatible housing is a XHP-2 receptacle, the jumper lead socket to socket to be used can be ASXHSXH22K305, or any other with AWG #30 to #22. The only constraint is that the current cannot excel 2000 mA, because the PicoBlades connectors used to interconnect the JST header to the EPS only supports 1000 mA per pin. For safe usage it is recommended to use the header with a maximum of 1500 mA charge current.

## 5.2 Debugging Though USB

Connecting a type A to micro type B USB cable to a PC and the USB port present on the FlatSat, the four USB to UART channels should be ready to be used. Note that the computer will recognize the port as four different devices. The FT4232H IC present on the platform doesn’t have an EEPROM, so it will be already configured to operate as default serial ports. The FT4232H will have the built-in default VID (0403) and PID (6011).

## 5.3 Debugging Though PC-104

Since all PC-104 interfaces are interconnected any slot can be used for probing and debbuging. Intentionally the slot N◦7 or also labeled “external interface” on the PCB was meant to be used for testing all pins. A new board or another FlatSat platform can be connected to this interface if the pinout of the specific project is compatible. The GOLDS-UFSC pinout is avalaible at its github repository [1].

## Bibliography

[1] SpaceLab. GOLDS-UFSC Mission Documentation, 2020. Available at <https://github.com/spacelab-ufsc/golds-ufsc-doc>. (https://github.com/spacelab-ufsc/golds-ufsc-doc)
[2] SpaceLab. FlatSat Platform, 2020. Available at <https://github.com/spacelab-ufsc/flatsat-platform>. (https://github.com/spacelab-ufsc/flatsat-platform)
[3] SpaceLab. | FlatSat draftsman documentation, 2020. | Available at <https:
//github.com/spacelab-ufsc/flatsat-platform/hardware/outputs/board_draftsman/board_ draftsman.pdf>. (https://github.com/spacelab-ufsc/flatsat-platform/hardware/outputs/board_draftsman/board_draftsman.pdf)
[4] Future Technology Devices International Ltd. USB Hardware Design Guidelines for FTDI ICs, 2014. Available at https://www.ftdichip.com/Support/Documents/AppNotes/AN_146_USB_Hardware_Design_Guidelines_for_FTDI_ICs.pdf. (https://www.ftdichip.com/Support/Documents/AppNotes/AN_146_USB_Hardware_Design_Guidelines_for_FTDI_ICs.pdf)

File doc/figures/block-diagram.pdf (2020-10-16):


Power Input A | USB USB/UART Converter UART Port 0 | UART Port 1 | UART Port 2 | UART Port 3 Power Output A | RBF Jumper RBF Connector | Kill-Switch A | Kill-Switch B KS A Connector | KS B Connector | Battery Charger Connector Battery Charger Input PC-104 A PC-104 D | PC-104 B | PC-104 C PC-104 E | PC-104 F PC-104 Ext. Power Input B (x6) | Power Output B (x6) Antenna Connector VHF Band Antenna Connector UHF Band Antenna Connector UHF Band Antenna Connector S Band | Antenna Connector VHF Band Antenna Connector UHF Band Antenna Connector UHF Band Antenna Connector S Band


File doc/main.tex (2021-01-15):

%
% main.tex
%
% Copyright (C) 2021 by SpaceLab.
%
% Flatsat Platfor Documentation
%
% This work is licensed under the Creative Commons Attribution-ShareAlike 4.0
% International License. To view a copy of this license,
% visit http://creativecommons.org/licenses/by-sa/4.0/.
%

%
% \brief Main file.
%
% \author Gabriel Mariano Marcelino <gabriel.marcelino@spacelab.ufsc.br>
% \author Yan Castro de Azeredo <yan.azeredo@spacelab.ufsc.br>
%
% \institution Universidade Federal de Santa Catarina (UFSC)
%
% \version 0.1.0
%
% \date 2020/07/16
%

\documentclass[a4paper,12pt]{book}

\usepackage{spacelab_book}

\title{Flatsat Platform Documentation}
\author{SpaceLab}
\date{\today}

% File metadata
\hypersetup
{
    pdfauthor   = {SpaceLab},
    pdfsubject  = {\thetitle},
    pdftitle    = {\thetitle},
    pdfkeywords = {Nanosatellites, CubeSats, Testbench, Flatsat}
}

\begin{document}

    \pagenumbering{roman}
    \setcounter{page}{1}

    \input{header/titlepage}
    \cleardoublepage
    \input{header/authorpage}
    \cleardoublepage

    \listoffigures
    \addcontentsline{toc}{chapter}{List of Figures}

    \listoftables
    \addcontentsline{toc}{chapter}{List of Tables}

    \printnomenclature
    \addcontentsline{toc}{chapter}{Nomenclature}

    \tableofcontents
    \cleardoublepage
    
    \pagenumbering{arabic}
    \setcounter{page}{1}

    \input{chapters/introduction}
    \input{chapters/system_overview}
    \input{chapters/hardware}
    \input{chapters/assembly}
    \input{chapters/instructions}
    \input{chapters/references}

\end{document}

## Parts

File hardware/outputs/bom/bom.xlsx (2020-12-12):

 |  |  | Bill of Materials
 |  |  | Source Data From: | flatsat_platform.PrjPcb
 |  |  | Project: | flatsat_platform.PrjPcb
 |  |  | Variant: | None
 |  |  | Project Code: | FLATSAT1
 |  |  | Report Date: | 11/5/2020 | 10:04 PM
 |  |  | Print Date: | 2020-11-05 | 22:04:35
# | Designator | Quantity | Manufacturer | Manufacturer Part Number | Partnumber | Description | #Column Name Error:' Package | Footprint | Mount | Fitted
1 | ANT1, ANT2, ANT3, ANT4, ANT5, ANT6, ANT7, ANT8 | 8 |  | 132134-15 |  | RF COAXIAL, SMA, STRAIGHT JACK, PCB; Connector Type:SMA Coaxial; Connector Body Style:Straight Jack; Coaxial Termination:Solder; Impedance:50ohm; Coaxial Cable Types:-; Contact Material:Brass; Contact Plating:Gold Plated Contacts |  | 132134-15 | Surface Mount,Through Hole | Fitted
2 | C1, C3, C4, C7, C9, C11, C13, C17, C18, C19, C20, C21, C22, C23 | 14 | TDK | C1608X7R1H104K080AA |  | TDK - C1608X7R1H104K080AA - SMD Multilayer Ceramic Capacitor, 0.1 µF, 50 V, 0603 [1608 Metric], ± 10%, X7R, C Series |  | C0603_MD | Surface Mount | Fitted
3 | C2, C5, C6, C10, C12 | 5 | TDK | C2012X7R1E475K125AB |  | Ceramic Capacitor SMD Multilayer, 0805 [2012 Metric], 4.7 uF, 25 V, 10%, X7R, C Series |  | C0805_MD | Surface Mount | Fitted
4 | C8, C14 | 2 | Kyocera AVX | 08055C103KAT4A |  | AVX - 08055C103KAT4A - SMD Multilayer Ceramic Capacitor, 10000 pF, 50 V, 0805 [2012 Metric], &#177; 10%, X7R |  | C0805_MD | Surface Mount | Fitted
5 | C15, C16 | 2 | Samsung | CL10C120JB8NNNC |  | Cap Ceramic 12pF 50VDC C0G 5% SMD 0603 Paper T/R |  | C0603_MD | Surface Mount | Fitted
6 | CN1, CN8 | 2 | Molex | 53398-0671 |  | 1.25mm Pitch PicoBlade™ Header, Surface Mount, Vertical, 6 Circuits |  | PICO BLADE 0533980671 | Surface Mount | Fitted
7 | CN2, CN3, CN15, CN16, CN17, CN18, CN19, CN20, CN21, CN22, CN23, CN24 | 12 | Samtec | SSW-126-01-G-D | [NoParam], SSW-126-01-G-D | Conn Socket Strip SKT 52 POS 2.54mm Solder ST Thru-Hole, 52 Position Receptacle Connector Through Hole |  | Inner_SSW-126-01-G-D_testboard, external_SSW-126-01-G-D _testboard, external_SSW-126-01-G-D, Inner_SSW-126-01-G-D | Through Hole | Fitted
8 | CN4, CN10 | 2 | Pomona Electronics | 4243-0 |  | POMONA, 4243-0, Binding Post, 4243 Series, 15 A, 60 VDC, Tin Plated Contacts, Brass, Black |  | 4243-0 | Panel | Fitted
9 | CN5 | 1 | Harwin | M20-9990245 |  | M20 HDR, PIN, SIL, VERT, 2W |  | CONN HEADER VERT 2POS 2.54mm | Through Hole | Fitted
10 | CN6, CN12, CN30 | 3 | Samtec | BCS-106-L-D-TE |  | CONN RCPT 12POS 0.1 GOLD PCB |  | BCS-106-L-D-TE | Through Hole | Fitted
11 | CN7 | 1 | JST | B2B-XH-A-M(LF)(SN) |  | CONN HEADER TOP 2POS 2.5MM GRN |  | B2B-XH-A-M(LF)(SN) | Through Hole | Fitted
12 | CN9, CN11 | 2 | Molex | 53398-0471 |  | Connector Header Surface Mount 4 position 0.049" (1.25mm) |  | PICO BLADE 0533980471 | Surface Mount | Fitted
13 | CN13, CN14 | 2 | Samtec | TSW-126-07-G-D |  | SAMTEC TSW-126-07-G-D Board-To-Board Connector, Vertical, TSW Series, 52 Contacts, Header, 2.54 mm, Through Hole, 2 Rows |  | Inner_TSW-126-07-G-D, external_TSW-126-07-G-D | Through Hole | Fitted
14 | CN25, CN27, CN28, CN29 | 4 | Molex | 53398-0371 |  | Conn Wire to Board HDR 3 POS 1.25mm Solder ST SMD Embossed T/R |  | PICO BLADE 0533980371 | Surface Mount | Fitted
15 | CN26 | 1 | FCI | 10118194-0001LF |  | CONN USB MICRO B RECPT SMT R/A |  | MICRO USB B 90GRAUS | Surface Mount,Horizontal | Fitted
16 | FB1, FB2, FB3 | 3 | Wurth Electronics | 742792608 |  | WURTH ELEKTRONIK 742792608 FERRITE BEAD, 0.1 OHM, 0.5A, 0603 |  | L0603 | Surface Mount | Fitted
17 | R1, R2 | 2 | Yageo | RC0603FR-0710RL |  | YAGEO (PHYCOMP) - RC0603FR-0710RL - RES, THICK FILM, 10R, 1%, 0.1W, 0603 |  | R0603_MD |  | Fitted
18 | R3 | 1 | Stackpole Electronics | RMCF0805FT12K0 |  | Resistor, SMT, 0805, 12K Ohm, +/-1%, +/-100ppm, Thk Film, T/R Marked |  | R0805_MD | Surface Mount | Fitted
19 | R4 | 1 | Vishay | CRCW08050000Z0EA |  | VISHAY - CRCW08050000Z0EA - SMD Chip Resistor, Jumper, 0805 [2012 Metric], 0 ohm, CRCW e3 Series, 150 V, Thick Film, 125 mW |  | R0805_MD |  | Fitted
20 | R5, R6, R7 | 3 | Vishay Dale | CRCW080510K0FKEA |  | RES 10.0K OHM 1/8W 1% 0805 SMD |  | R0805_MD |  | Fitted
21 | SW1, SW2 | 2 |  | 100SP1T1B4M2QE |  | E-SWITCH - 100SP1T1B4M2QE - SWITCH, TOGGLE, SPDT, 5A, 120VAC, 28VDC |  | Toggle Switch SPDT Through Hole | Through Hole | Fitted
22 | U1 | 1 | FTDI | FT4232HL-REEL |  | FTDI - FT4232HL-REEL - USB-UART/MPSSE, 4232, QUAD, 64LQFP |  | LQFP-64 | Surface Mount | Fitted
23 | U2 | 1 | Texas Instruments | TPS79333DBVR |  | TEXAS INSTRUMENTS - TPS79333DBVR - IC, V REG, LINEAR, 0.2A, SOT-23-5 |  | SOT23-5 |  | Fitted
24 | XTAL1 | 1 | TXC | AA-12.000MAGE-T |  | Crystals 12.000MHz 30ppm 12pF -40C to 85C |  | TXC 7A Series | Surface Mount | Fitted

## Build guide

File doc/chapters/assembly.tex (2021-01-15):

%
% assembly.tex
%
% Copyright (C) 2021 by SpaceLab.
%
% Flatsat Platform Documentation
%
% This work is licensed under the Creative Commons Attribution-ShareAlike 4.0
% International License. To view a copy of this license,
% visit http://creativecommons.org/licenses/by-sa/4.0/.
%

%
% \brief Board Assembly chapter.
%
% \author Gabriel Mariano Marcelino <gabriel.marcelino@spacelab.ufsc.br>
% \author Yan Castro de Azeredo <yan.azeredo@spacelab.ufsc.br>
%
% \institution Universidade Federal de Santa Catarina (UFSC)
%
% \version 0.1.0
%
% \date 2020/24/12
%

\chapter{Board Assembly}

The hardware project has the Bill of Material (BOM\nomenclature{\textbf{BOM}}{\textit{Bill Of Materials.}}) avalaible at its GitHub repository in excel spreeadsheets format. The PCB can be assembled by a Pick-and-place machine using the .txt file found on the hardware/fabrication folder if desired, fiducials labeled FD\# are placed to make this possible.

\section{FlatSat Stabillity Feet}

On the PCB there are labeled MEC1 to MEC12 mouting holes on the edges and in the middle of the board to be used for stabillity feet when the board is placed on top of a test bench.

\section{DNP Components}

There is only one Do Not Place (DNP\nomenclature{\textbf{DNP}}{\textit{Do Not Place.}}) component present in the USB to UART circuit, it is the labeled R4 pad with 0805 size (2012 metric) available for soldering the micro USB type B chassi to GND for Electromagnetic compatibility (EMC\nomenclature{\textbf{EMC}}{\textit{Electromagnetic Compatibility.}}) see \autoref{fig:R4-pad}. This can be done soldering a zero-Ohm resistor for a DC\nomenclature{\textbf{DC}}{\textit{Direct Current.}} path or capacitor for a high-frequency path between shield and signal ground, see Section 2.2.2 of the document \cite{ftdi-usb-hardware-guidelines} for more details.

\begin{figure}[!ht]
    \begin{center}
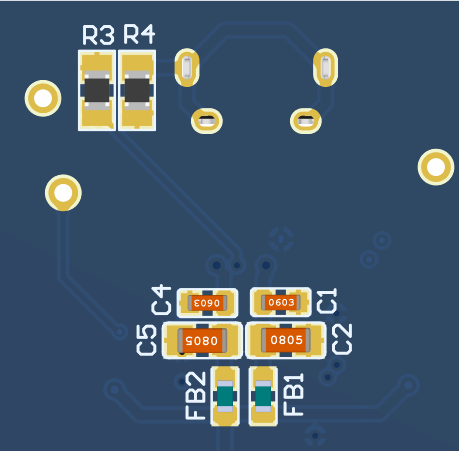
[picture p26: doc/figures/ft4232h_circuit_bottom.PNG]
        
        \caption{Bottom view of the UART to USB converter circuit.}
        \label{fig:R4-pad}
    \end{center}
\end{figure}

\section{Modules Mounting}

The PC-104 slots N$^{\circ}$2 to N$^{\circ}$7 are compatible for CubeSat PCB modules that are stacked in middle or the first on top. The slot N$^{\circ}$1 can only be used for the last module on this stack because of the inverted pinout. For the case of the SpaceLab's CubeSat stackup of the core modules, the last module of the stack is the EPS. For this case the EPS needs to be mounted up-side-down on slot N$^{\circ}$1 as can be seen on \autoref{fig:eps2-mouting}. For other modules any other PC-104 slots can be used, the OBDH\nomenclature{\textbf{OBDH}}{\textit{On-Board Data Handling.}} is showed mouted on \autoref{fig:obdh2-mouting}.

\begin{figure}[!ht]
    \begin{center}
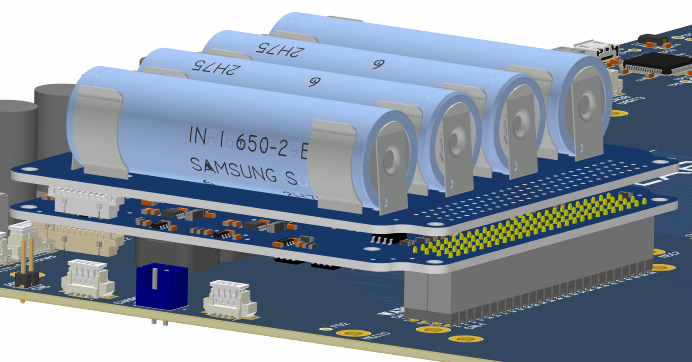
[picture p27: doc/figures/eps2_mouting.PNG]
        
        \caption{EPS mounted on N$^{\circ}$1 slot on a EDA tool.}
        \label{fig:eps2-mouting}
    \end{center}
\end{figure}

\begin{figure}[!ht]
    \begin{center}
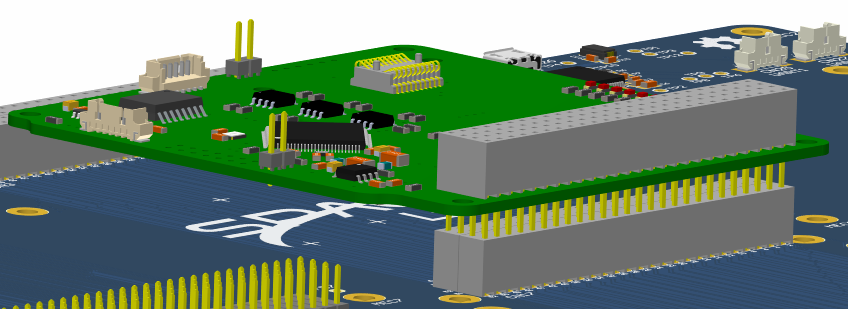
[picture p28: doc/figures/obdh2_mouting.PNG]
        
        \caption{OBDH mounted on N$^{\circ}$2 slot on a EDA tool.}
        \label{fig:obdh2-mouting}
    \end{center}
\end{figure}

\section{Antennas Connection}

Since the SMA connectors present on the board are on the right far side, modules placed in the opposite side may not be in reach for the connection. Because of this reason is recommended to use slots N$^{\circ}$1 and N$^{\circ}$4 for non antenna dependents PCBs.

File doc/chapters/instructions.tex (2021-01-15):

%
% intructions.tex
%
% Copyright (C) 2021 by SpaceLab.
%
% Flatsat Platform Documentation
%
% This work is licensed under the Creative Commons Attribution-ShareAlike 4.0
% International License. To view a copy of this license,
% visit http://creativecommons.org/licenses/by-sa/4.0/.
%

%
% \brief Usage Instructions chapter.
%
% \author Yan Castro de Azeredo <yan.azeredo@spacelab.ufsc.br>
%
% \institution Universidade Federal de Santa Catarina (UFSC)
%
% \version 0.1.0
%
% \date 2020/04/01
%

\chapter{Usage Instructions} \label{ch:instructions}

\section{Charging Batteries Through Connector}

To charge the batteries it will be needed a cable compatible with the JST XH header. The compatible housing is a XHP-2 receptacle, the jumper lead socket to socket to be used can be \textit{ASXHSXH22K305}, or any other with AWG\nomenclature{\textbf{AWG}}{\textit{American Wire Gauge.}} \#30 to \#22. The only constraint is that the current cannot excel 2000 mA, because the PicoBlades connectors used to interconnect the JST header to the EPS only supports 1000 mA per pin. For safe usage it is recommended to use the header with a maximum of 1500 mA charge current.

\section{Debugging Though USB}

Connecting a type A to micro type B USB cable to a PC\nomenclature{\textbf{PC}}{\textit{Personal Computer.}} and the USB port present on the FlatSat, the four USB to UART channels should be ready to be used. Note that the computer will recognize the port as four different devices. The FT4232H IC present on the platform  doesn't have an EEPROM\nomenclature{\textbf{EEPROM}}{\textit{Electrically-Erasable Programmable Read-Only Memory.}}, so it will be already configured to operate as default serial ports. The FT4232H will have the built-in default VID (0403) and PID (6011).

\section{Debugging Though PC-104}

Since all PC-104 interfaces are interconnected any slot can be used for probing and debbuging. Intentionally the slot N$^{\circ}$7 or also labeled ``external interface'' on the PCB was meant to be used for testing all pins. A new board or another FlatSat platform can be connected to this interface if the pinout of the specific project is compatible. The GOLDS-UFSC pinout is avalaible at its github repository \cite{golds-ufsc}.

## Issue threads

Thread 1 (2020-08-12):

Define the architecture

mgm8, 2020-08-12:
Some possible architectures:

**1. Single board as a dock:**

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

**2. Single board as a bridge between the modules:**

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
[https://github.com/JonisK/FlatSat](https://github.com/JonisK/FlatSat)

**3. Modular boards:**

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

mgm8, 2020-09-22:
Chosen architecture: **1.**

Closed 2020-09-22.

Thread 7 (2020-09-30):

Add two switches to emulate the kill-switches of the satellite

mgm8, 2020-09-30:
The switches can be any type of 2-position and 3 pins switch.

Two 6-pin PicoBlade connectors must be included to allow the connection between the test bed and the EPS board.

Closed 2020-10-17.

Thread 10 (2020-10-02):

Add SMA connectors

mgm8, 2020-10-02:
Add SMA connectors (x4) to allow the connection of antennas to the test bed. Two connectors per channel must be used: one to connect the transceiver and one to connect the antenna.

* x1 VHF band
* x2 UHF band
* x1 S Band

Suggested part number: [SMA CONNECTOR](https://br.mouser.com/ProductDetail/LPRS/SMA-CONNECTOR?qs=j%252B1pi9TdxUYkOiITvzJM8A%3D%3D)

Example:
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

YanAzer, 2020-10-03:
@mgm8 this [one](https://www.amphenolrf.com/132134-15.html) can be used?

Closed 2020-10-17.

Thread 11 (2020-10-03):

Add a battery charger connector

mgm8, 2020-10-03:
Add a battery charger connector and a PicoBlade connector (to connect the battery charger interface to the EPS module).

Closed 2020-10-17.

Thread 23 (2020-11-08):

Hardware: Fix assembly top and bottom drawings for full PDF document

YanAzer, 2020-11-08:

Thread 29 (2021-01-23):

Hardware: Add a circuit to emulate the antenna deployer circuit

andrempmattos, 2021-01-23:
Using as reference our ISIS antenna emulator, create the hardware circuit to complete the emulation at the physical level.

https://github.com/spacelab-ufsc/antenna-deployer-emulator

In other word, create a simple resistive load circuit to draw power from EPS that is controlled with a external MSP430 launchpad. The circuit should be something similar to:

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

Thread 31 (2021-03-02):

Documentation: Improve Board Assembly chapter

YanAzer, 2021-03-02:
- Include "Recommended configuration for fabrication" section and table;
- Include "Solder sequence" section;
- Include "Cables" section;

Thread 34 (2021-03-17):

Hardware: Fix values of the layer stack table according manufacturer

YanAzer, 2021-03-17:
https://www.pcbway.com/multi-layer-laminated-structure.html

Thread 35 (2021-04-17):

Hardware: Separate the RF GND from the "normal" GND

mgm8, 2021-04-17:
The GND from the SMA connectors is connected to the common GND of the board.

mgm8, 2021-04-17:
https://github.com/spacelab-ufsc/flatsat-platform/issues/36

Closed 2021-04-17.

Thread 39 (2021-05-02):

Hardware: Fix the part number of the SMA conector

mgm8, 2021-05-02:
The center pin of the [132134-15](https://www.digikey.com/en/products/detail/amphenol-rf/132134-15/3088347) connector is SMD, we need a part number with the center pin also through-hole.

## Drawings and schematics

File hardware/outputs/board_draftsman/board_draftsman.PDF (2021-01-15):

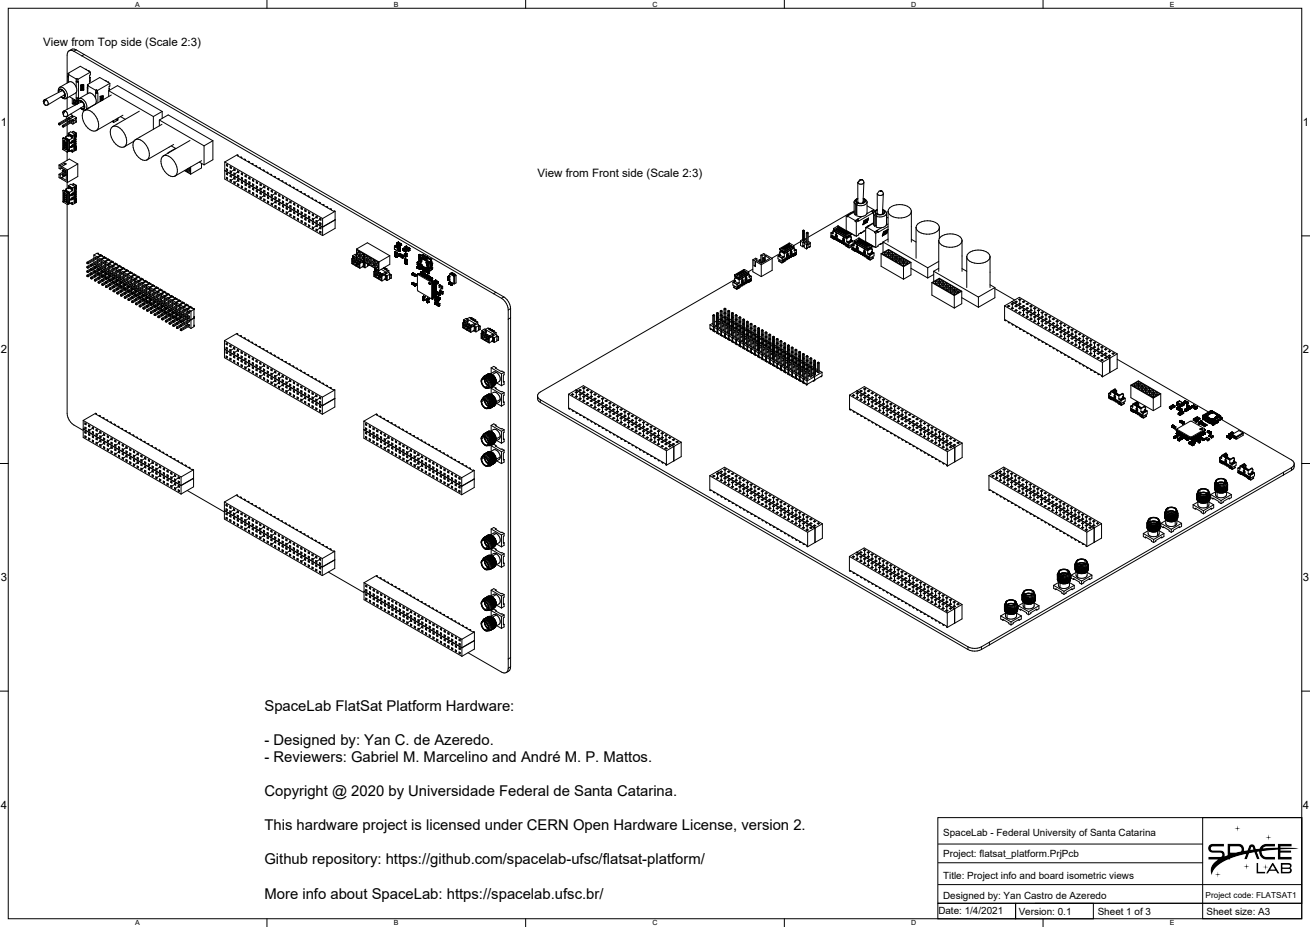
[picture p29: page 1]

View from Top side (Scale 2:3)

View from Front side (Scale 2:3)

SpaceLab FlatSat Platform Hardware:

- Designed by: Yan C. de Azeredo.
- Reviewers: Gabriel M. Marcelino and André M. P. Mattos.

Copyright @ 2020 by Universidade Federal de Santa Catarina.

This hardware project is licensed under CERN Open Hardware License, version 2.

SpaceLab - Federal University of Santa Catarina

Github repository: https://github.com/spacelab-ufsc/flatsat-platform/

Title: Project info and board isometric views
Designed by: Yan Castro de Azeredo

More info about SpaceLab: https://spacelab.ufsc.br/

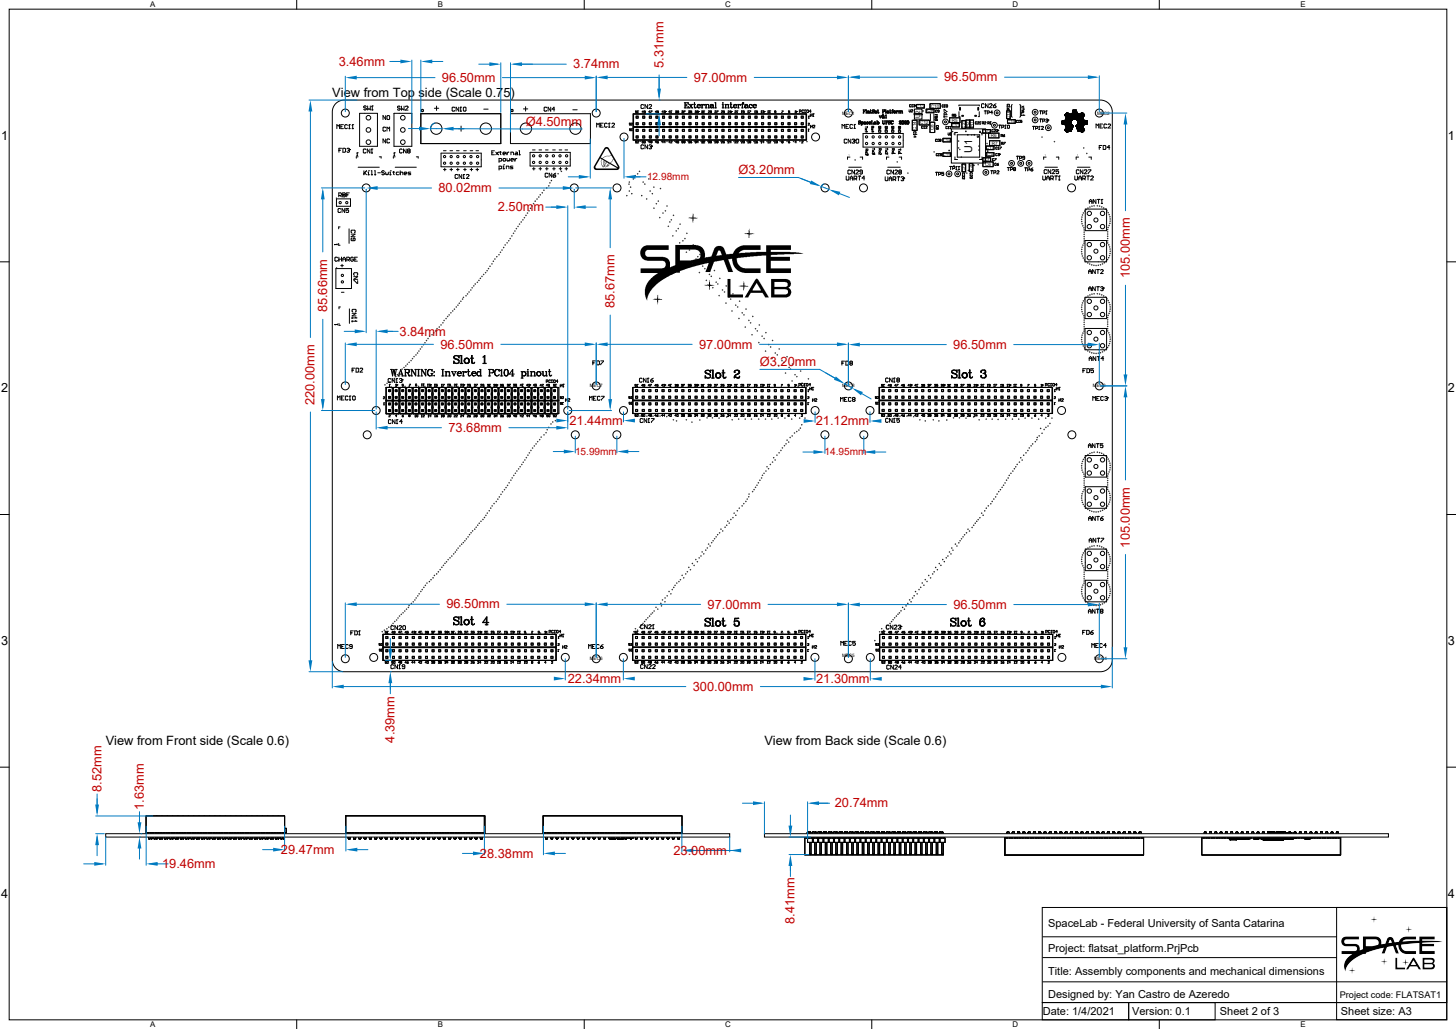
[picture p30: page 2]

View from Top side (Scale 0.75)

View from Front side (Scale 0.6)

View from Back side (Scale 0.6) 8.41mm

SpaceLab - Federal University of Santa Catarina

Title: Assembly components and mechanical dimensions

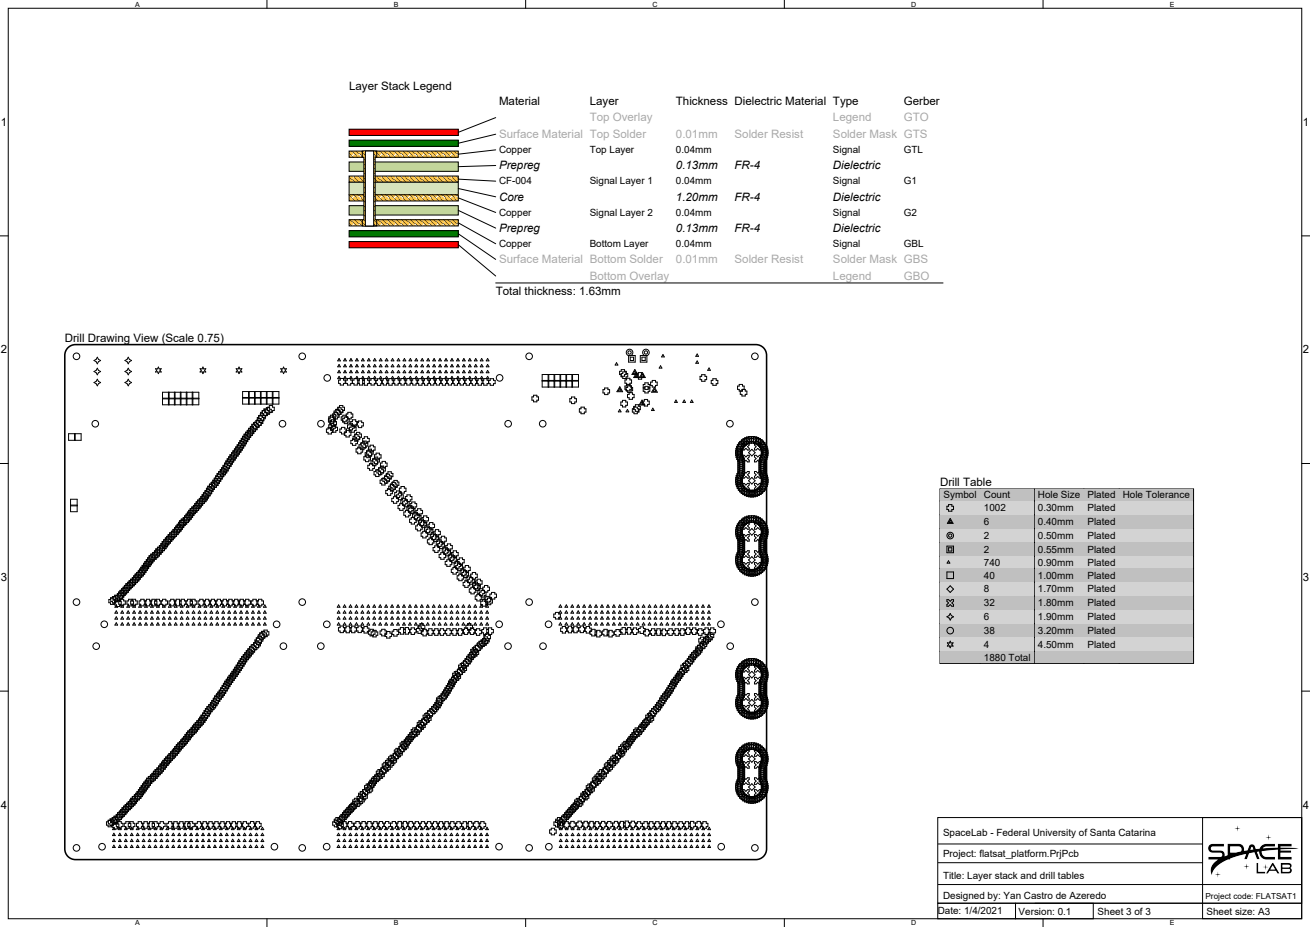
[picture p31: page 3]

Drill Drawing View (Scale 0.75)

Symbol | Count | Hole Size | Plated | Hole Tolerance

1002 | 0.30mm | Plated
6 | 0.40mm | Plated
2 | 0.50mm | Plated
2 | 0.55mm | Plated
740 | 0.90mm | Plated
40 | 1.00mm | Plated
8 | 1.70mm | Plated
32 | 1.80mm | Plated
6 | 1.90mm | Plated
38 | 3.20mm | Plated
4 | 4.50mm | Plated
1880 Total

SpaceLab - Federal University of Santa Catarina

Title: Layer stack and drill tables

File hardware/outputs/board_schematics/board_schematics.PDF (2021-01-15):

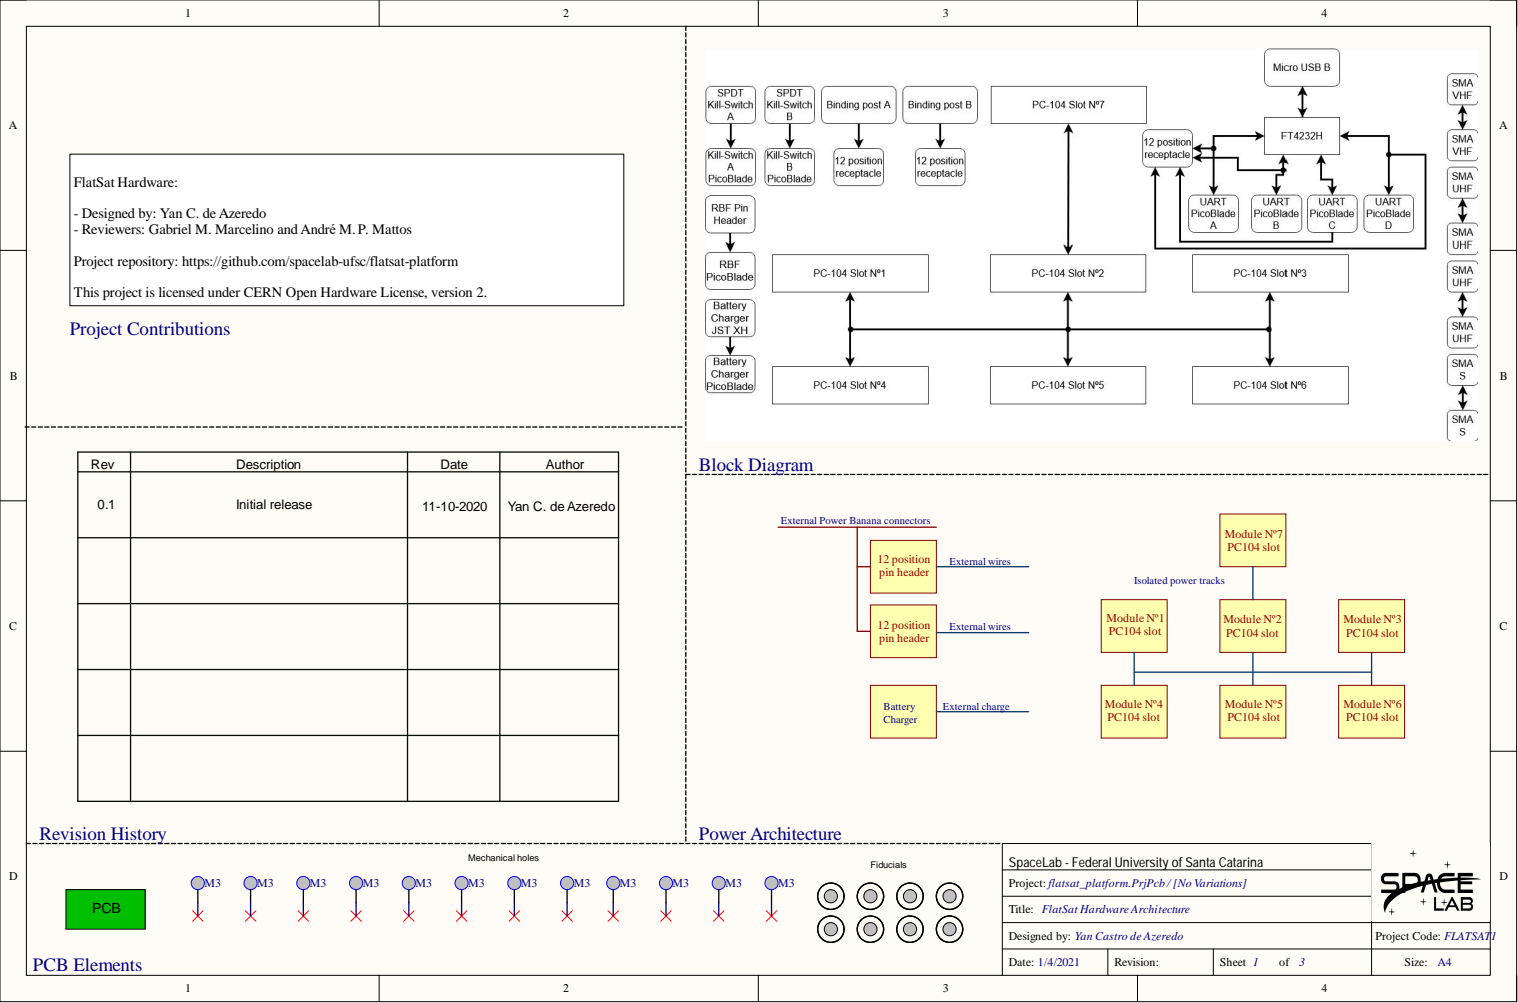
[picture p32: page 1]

R e v | D escri p t i o n | D a t e | A u t h o r

0 . 1 | I n i t i a l re l e ase | 1 1-1 0 -2 0 2 0 | Ya n C . d e Azere d o

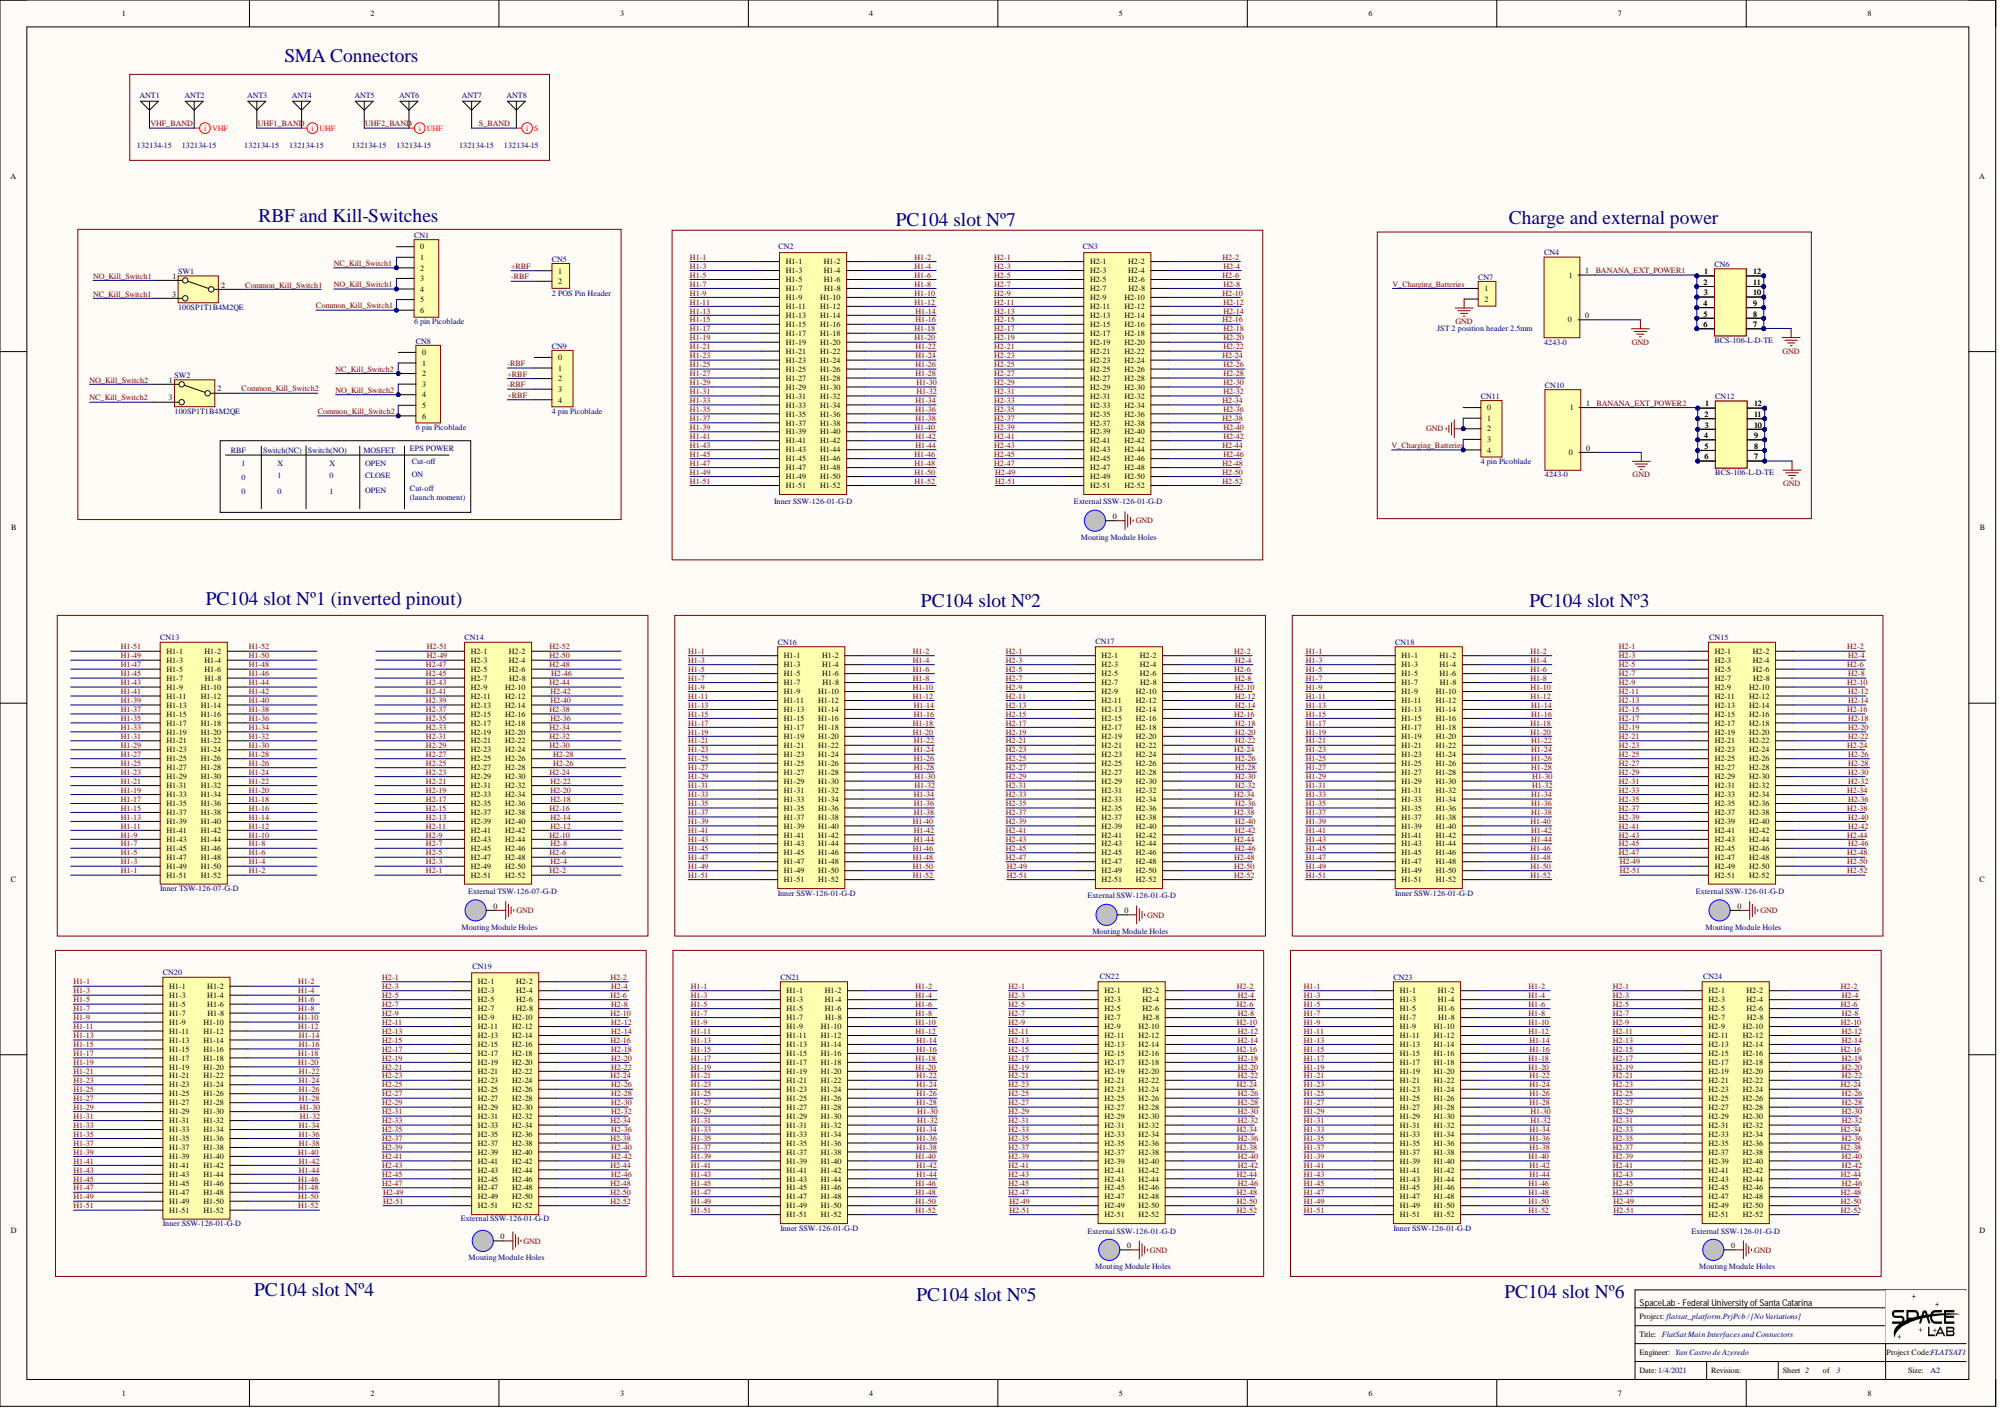
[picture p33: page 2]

Charge and external power

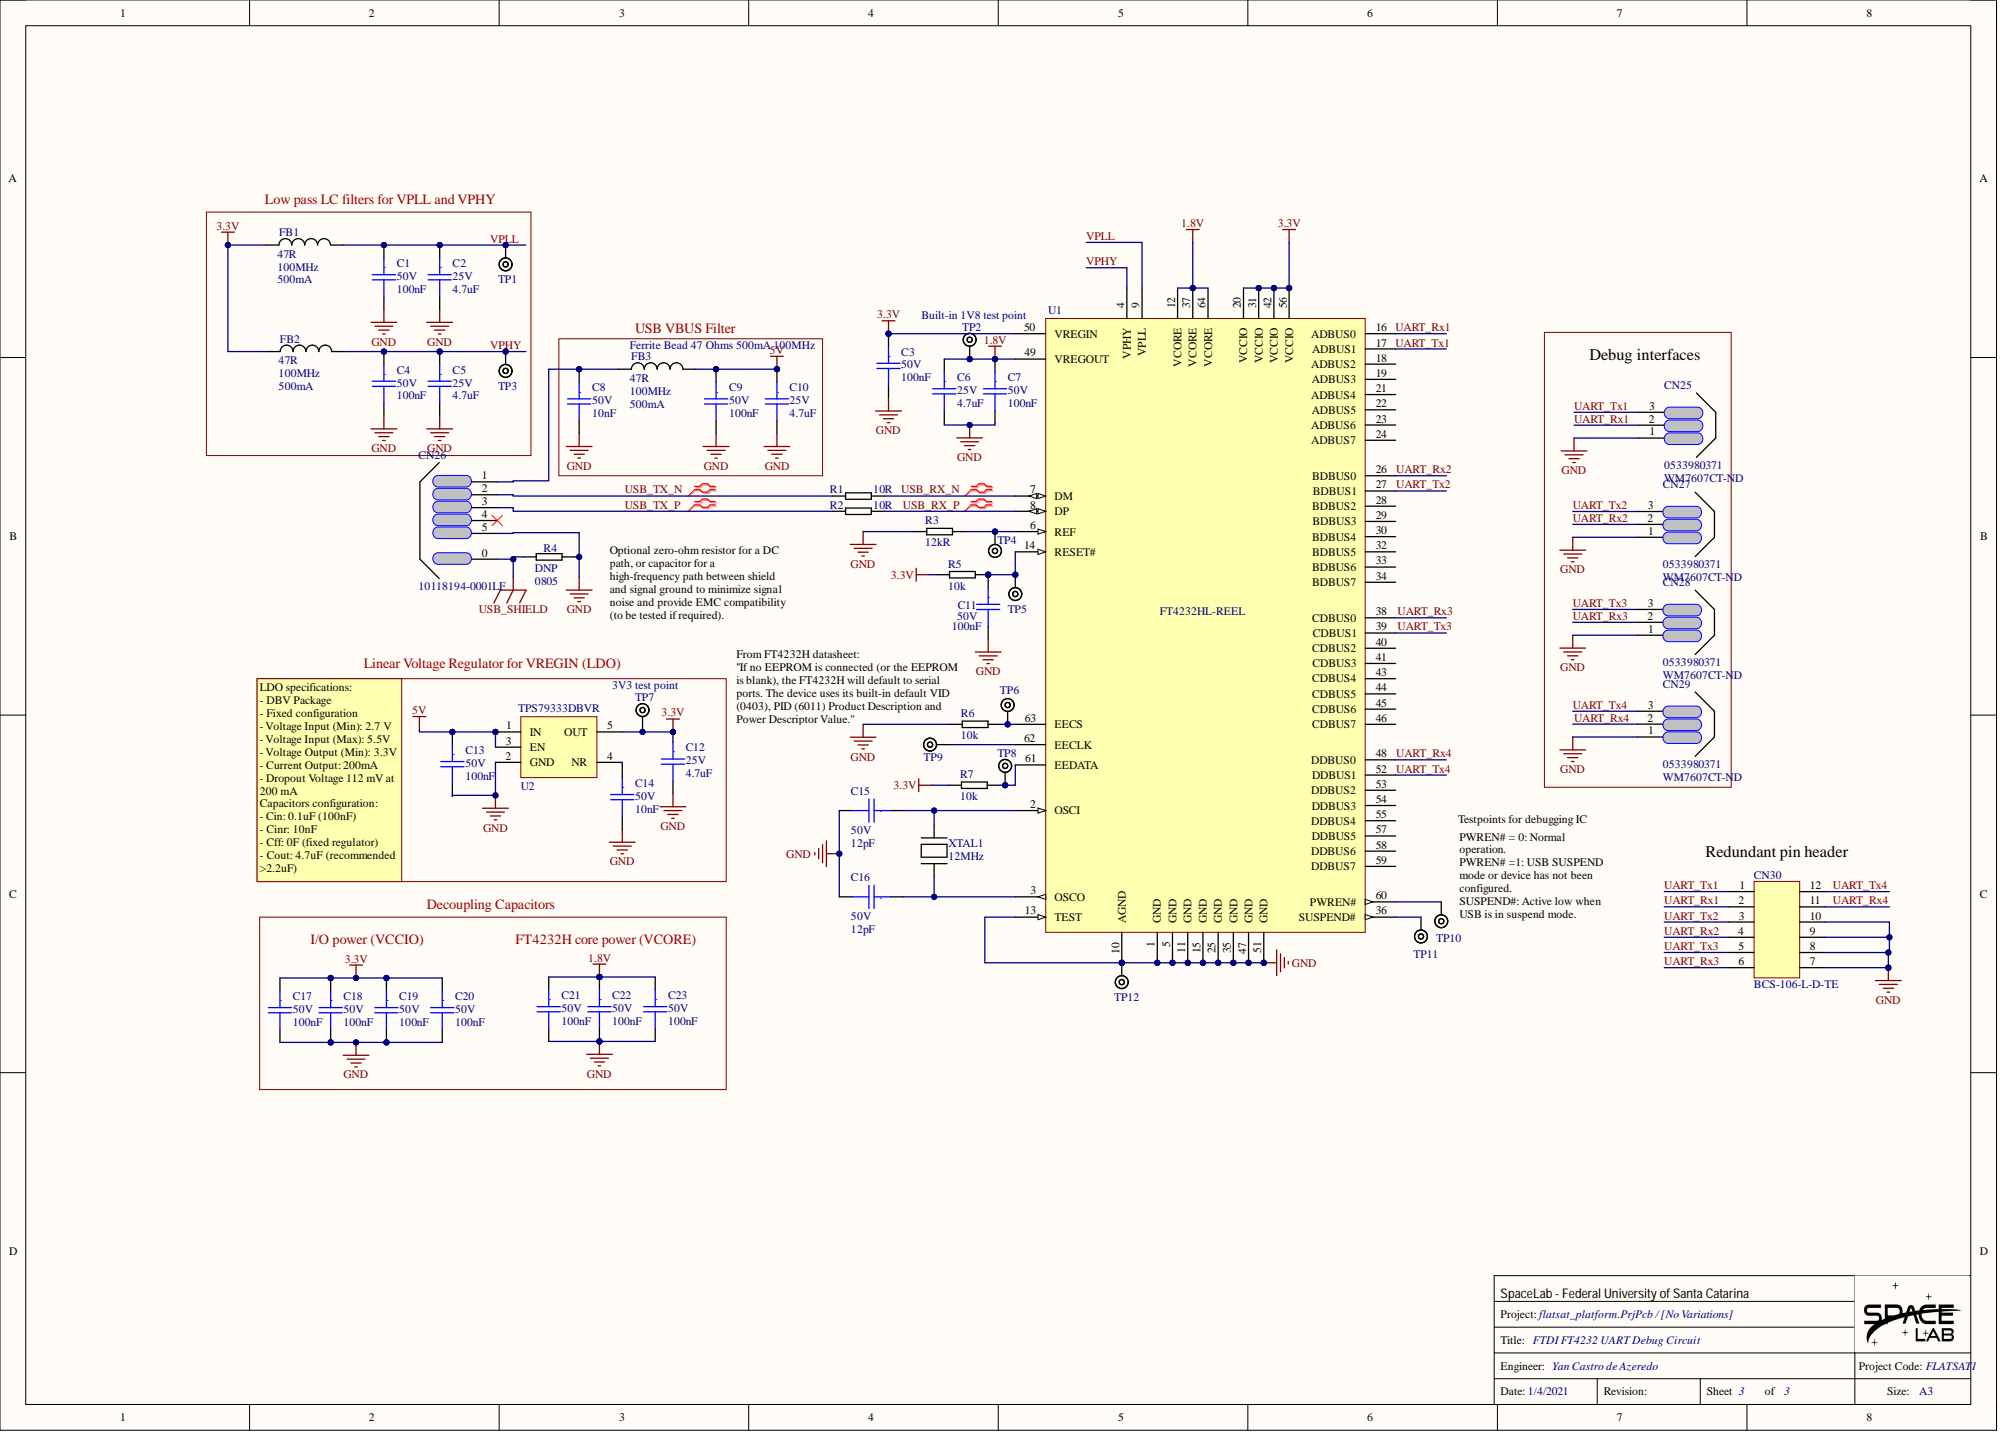
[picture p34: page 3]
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

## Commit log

2020-09-22 hardware: Adding first gitignore and files for the flatsat project
    [0_architecture.SchDoc, 1_flatsat_interfaces.SchDoc, board_layout.PcbDoc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]
2020-09-24 hardware: sources: Adding pinout to PC104 connectors in a A2 schematic sheet #2
    [1_flatsat_interfaces.SchDoc]
2020-09-29 hardware: sources: Adding usb debug schematic #2
    [2_usb_debug.SchDoc]
2020-09-29 hardware: libraries: Updating PC104 connector in two independent parts and adding new components to libraries
2020-10-02 hardware: sources: Adding picoblade connectors for RBF and kill-switches on main interfaces schematic #2 #7 #8
    [1_flatsat_interfaces.SchDoc]
2020-10-03 hardware: sources: Adding a 2 pin header (jumper) for RBF and two SPDT switches for the kill-switches on 1_flatsat_interfaces schematic #2 #7 #8
    [1_flatsat_interfaces.SchDoc]
2020-10-03 hardware: sources: schematics: Adding battery charger connector and a PicoBlade connector #2 #11
    [1_flatsat_interfaces.SchDoc]
2020-10-09 hardware: outputs: board_schematics: Uploading first schematic for the project
2020-10-10 hardware: sources: schematics: Reorganizing components positioning and solving issues closes #4 #7 #8 #10 #11 #13
    [1_flatsat_interfaces.SchDoc]
2020-10-10 hardware: sources: schematics: Changing USB port and adding 3 pin picoblades for UART debugging
    [2_usb_debug.SchDoc]
2020-10-10 hardware: sources: layout: Routed most of the PC104 connections and positioned components and screws close #3
2020-10-10 hardware: sources: schematics: Making UHF net labels different from one SMA connector to another and changing parameter set, now with net net classes
    [1_flatsat_interfaces.SchDoc]
2020-10-11 hardware: soureces: layout: Routed all nets, done minimal pcb code revision with labels, tenting vias, teardrops and shielding
2020-10-11 hardware: sources: schematics: Adding revision history info for 0.1v release
    [0_architecture.SchDoc]
2020-10-11 hardware: sources: layout: Fixing all vias for minimal 0.3mm hole size, repositioning fiducials and minor changes to labels
2020-10-11 hardware: fabrication and outputs: Uploading first fabrication, schematics, board prints and camtastic files
2020-10-12 hardware: soureces: schematics: Adding project repository link and licence to architecture sheet
    [0_architecture.SchDoc]
2020-10-13 hardware: sources: layout: Improving antennas shielding, fixing binding post (banana connector) hole size and UART picoblades positioning
2020-10-13 hardware: sources: schematics: Adding redundant pin header for UART debugging
    [2_usb_debug.SchDoc]
2020-10-13 hardware: sources: layout: Adding extra pin header for UART debugging
2020-10-13 hardware: sources: layout: Tenting missing new via, fixing label distance on 3 pin picoblades and removing 3D models of the modules from PCB document
2020-10-13 hardware: Refreshing project file
    [flatsat_platform.PrjPcb]
2020-10-13 hardware: fabrication and outputs: Adding updated fabrication files (also deleting old one) and minimal outputs (schematics and board prints)
2020-10-13 hardware: libraries: Updating banana connector and 3 pin picoblade footprints
2020-10-27 hardware: libraries: updating schematic symbols and footprint of pc104 connectors, now with mounting holes and including the new TSW-126-07-G-D component #12
2020-10-27 hardware: sources: schematic: Reannotating components labels, including GND for mouting holes on all PC104 connectors and including the vertical PC104 interface for the EPS module with inverted label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
    [1_flatsat_interfaces.SchDoc]
2020-10-27 hardware: sources: schematic: Reannotating components labels and fixing non-connected pin for UART header
    [2_usb_debug.SchDoc]
2020-10-27 hardware: sources: layout: Updating all PC104 footprints and removing 3D models of mating modules
2020-11-06 hardware: sources: Minor component parameters and pcb color fixes
    [0_architecture.SchDoc, 2_usb_debug.SchDoc]
2020-11-06 hardware: outputs: bom: Adding bill of materials close #17
    [bom.xlsx]
2020-11-06 hardware: outputs: Generating output files for project v0.1
    [Gerber.GM1, gerber.GBL, gerber.GBO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]
2020-11-07 doc: figures: Adding first top, bottom and perspective images of PCB
2020-12-15 hardware: libraries: Deleting repeated USB schematic symbol
2020-12-15 hardware: Refreshing altium project control file now with added draftsman source file to project tree
    [flatsat_platform.PrjPcb]
2020-12-31 doc: chapters: Adding missing SMA connectors description on the introduction chapter
2021-01-03 doc: Including assembly chapter to main.tex
2021-01-03 doc: chapters: Adding first version of the assembly chapter
2021-01-03 doc: figures: Adding figures to be used for the assembly chapter
2021-01-03 doc: chapters: Minor update to PC104 interfaces section text and updating caption on top view of the USB to UART converter circuit figure
2021-01-04 hardware: outputs: board_draftsman: Adding draftsman PDF of the board #24
2021-01-04 hardware: Updating project file tree with draftsman source file #24
    [flatsat_platform.PrjPcb]
2021-01-04 doc: chapters: Fixing typos on the assembly chapter
2021-01-04 doc: figures: Updating rbf connectors image to blue solder mask and new SpaceLab's 2021 logo
2021-01-05 hardware: sources: Updating and embedding block diagram figure on architecture schematic sheet close #22
    [0_architecture.SchDoc]
2021-01-05 hardware: outputs: board_schematics: Updating PDF with new block diagram image

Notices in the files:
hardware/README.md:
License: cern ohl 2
